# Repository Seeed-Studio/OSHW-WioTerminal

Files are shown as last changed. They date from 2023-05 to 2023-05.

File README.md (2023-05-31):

# Wio Terminal: Fabricatable Open Source Hardware

wio terminal

## Overview

Seeed Studio is committed to the open-source hardware movement, and in that spirit, we have taken this a step further into open manufacturing. We wish to make it possible for anyone to reproduce and manufacture this device. We believe that opening the manufacturing process will unlock immense potential for innovation and creativity.

Welcome to the Wio Terminal project, an open-source hardware initiative developed and maintained by Seeed Studio. The Wio Terminal is not just a highly integrated microcontroller, it is also a widely acknowledged and used IoT development platform. Compatible with Arduino and MicroPython, it supports both Bluetooth and Wi-Fi, providing strong support for IoT projects. Whether it is in smart homes, industrial automation, or educational research, Wio Terminal exhibits its powerful functionality and versatility.

With sincerity and practicality, we are now providing all the files and information required for manufacturing, enabling anyone to freely replicate, produce, and even commercialize the Wio Terminal. We believe that open manufacturing will facilitate innovation, allowing more people to participate in hardware design and improvement, and collectively promote the development of hardware technology. We look forward to seeing your versions and encourage you to share your designs and ideas on this platform.

## What we provided before

- The open source design files can be found in the ["resources" section](https://wiki.seeedstudio.com/Wio-Terminal-Getting-Started#resources) located below our products wiki.
- These design files are freely available for anyone to access, use and modify.

## What we are offering now

This repository contains all the necessary documentation you need to manufacture Wio Terminal:

- Schematic Diagrams (PDF)
- Gerber Files
- Firmware Source Code
- Bill of Materials (BOM)
- Production Testing Plan
- Production SOP
- 3D Models of the Enclosure

For the convenience, we also include here the design files in the Wio Terminal wiki.

## Documentation

For more information on the Wio Terminal, please refer to the following links:

- [Learn or Buy](https://www.seeedstudio.com/Wio-Terminal-p-4509.html)
- [Wio Terminal Wiki](https://wiki.seeedstudio.com/Wio-Terminal-Getting-Started)

## Fusion Quick Pass

For those who wish to design and manufacture their own versions of Wio Terminal, our [Fusion service](https://www.seeedstudio.com/fusion.html) offers quick and high-quality services. We also encourage you to share your own versions of Wio Terminal for display and exchange with the community.

## [A Chance To Get 2PCS Free PCBA from Seeed Fusion](https://www.seeedstudio.com/blog/2023/05/25/from-concept-to-creation-join-the-wio-terminal-movement-and-fabricate-your-own-open-source-hardware-for-a-chance-to-get-2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)

In order to give back to our community and make your great ideas a reality, Seeed Studio Fusion is launching the Wio Terminal open source movement to help capable engineers, individual developers turn their designs into real products.

For those who wish to design and manufacture their own versions of Wio Terminal, our SeeedStudio Fusion Agile manufacturing offers quick and high-quality PCB Assembly service. One more thing to clarify is that please make sure that you are capable of designing and have all the production files ready for us. Moreover, once your idea/proposal is approved by us, each person is limited to two PCBA boards 100% completely FREE for one Wio Terminal design, including PCB fabrication, the cost of parts, assembly and free worldwide delivery.

Please fill out the form: https://forms.gle/uic7bVA8SnuJLFR3A to submit your Wio Terminal design proposal. 

wioterminal

## License

This project is licensed under the [Apache-2.0 License](/LICENSE). By using, distributing, or contributing to this project, you agree to the terms and conditions of this license.

## Let's Open Manufacturing Together!

We're excited to take this journey with you. Let's create, innovate, and shape the future of open manufacturing together!

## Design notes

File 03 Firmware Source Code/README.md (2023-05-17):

Here is the firmware source code for Wio Terminal.

And here are the firmware source GitHub repositories links:

- Arduino-samd firmware for getting started with Wio Terminal: https://github.com/Seeed-Studio/ArduinoCore-samd

- SenseCraft firmware for supporting data Cloud upload: https://github.com/Seeed-Studio/SenseCraft

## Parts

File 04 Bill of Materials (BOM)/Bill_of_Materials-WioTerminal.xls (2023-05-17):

SKU | Spec | MPN | Reference | Base | Qty | Unit
102991299 | Wio Terminal (D51R)
202002756 | PCBA;Wio Terminal (D51R) |  |  | 1 | 1 | PCS
202002927 | PCBA;BT+WiFi Module;32P-L14*W12mm |  | U10 | 1 | 1 | PCS
206001065 | SMD IC NOR Flash;16Mbit-SPI;USON-8_software outsourcing_RTL8720DN v2.2 |  | U2 | 1 | 1 | PCS
310091053 | SMD IC NOR Flash;16Mbit-SPI;USON-8;2*3mm | GD25Q16CEIGR |  | 1 | 1 | PCS
301010525 | SMD RES 0R-±1%-1/20W;0201 | RC0201FR-070RL | L1, L2 | 1 | 2 | PCS
301010526 | SMD RES 10K-±1%-1/20W;0201 | RC0201FR-0710KL | R3, R8 | 1 | 2 | PCS
301010765 | SMD RES 100K-±1%-1/20W;0201 | RC0201FR-07100KL | R5 | 1 | 1 | PCS
302010053 | SMD CAP Ceramic 10uF-6.3V-20%-X5R;0402 | CC0402MRX5R5BB106 | C30 | 1 | 1 | PCS
302010233 | SMD CAP Ceramic 2.2uF-6.3V-20%-X5R;0402 | CC0402MRX5R5BB225 | C2, C3, C8 | 1 | 3 | PCS
302010271 | SMD CAP Ceramic 100nF-10V-10%-X5R;0201 | CC0201KRX5R6BB104 | C1, C4, C5, C6, C7, C9, C10, C11, C12, C18 | 1 | 10 | PCS
302010367 | SMD CAP Ceramic;10pF-25V-5%-NP0;0201 | CC0201JRNPO8BN100 | C19, C20 | 1 | 2 | PCS
302010730 | SMD CAP Ceramic 1uF-10V-20%-X5R;0201 | GRM033R61A105ME44D | C13, C15, C16 | 1 | 3 | PCS
302012228 | SMD CAP Ceramic 1pF±0.1pF-50V-COG/NPO;0201 | GRM0335C1H1R0BA01D | L3 | 1 | 1 | PCS
303010058 | SMD Inductor 2.2uH-20%-350mA;0402 | MLZ1005M2R2WT000 | L4 | 1 | 1 | PCS
306011034 | SMD Crystal 40MHz-10pF-10ppm-60R;4P-L2.0*W1.6mm | FA-128 40.000000MHZ 10PF 10PPM | X1 | 1 | 1 | PCS
306050436 | SMD Filter;6P 2.4G-5GHz 1.6*0.8*0.6mm | DPX165950DT-8148A1 | U3 | 1 | 1 | PCS
310011276 | SMD MCU;QFN48 | RTL8720DN-VA1-CG | U1 | 1 | 1 | PCS
319014199 | PCB;BT+WiFi Module_V1.1-black oil white legend-4 layers |  | PCB | 1 | 1 | PCS
323040420 | BT+WiFi Module_Shielding cover v3.0; 0.2mm white copper - laser engraving-13.5*11.5*1.7mm |  | SH1 | 1 | 1 | PCS
301010000 | SMD RES 0R-5%-1/16W;0402 | RC0402JR-070RL | R5, R8, R12, R17, R21, R39, R40, R41, R42, R46, R53, R68, R69, R72, R79, R83 | 1 | 16 | PCS
301010006 | SMD RES 1K-5%-1/16W;0402 | RC0402JR-071KL | R25, R28, R31, R47, R51, R88, R99 | 1 | 7 | PCS
301010010 | SMD RES 4.7K-5%-1/16W;0402 | RC0402JR-074K7L | R3, R4, R13, R11, R14, R20, R38, R48, R49, R54, R61, R62, R63 | 1 | 13 | PCS
301010047 | SMD RES 10K-1%-1/16W;0402 | RC0402FR-0710KL | R9, R22, R26, R27, R77, R94, R96, R97, R98 | 1 | 9 | PCS
301010052 | SMD RES 22R-1%-1/16W;0402 | RC0402FR-0722RL | R55, R56 | 1 | 2 | PCS
301010441 | SMD RES 33K-1%-1/16W;0402 | RC0402FR-0733KL | R71 | 1 | 1 | PCS
301010456 | SMD RES 100K-1%-1/16W;0402 | RC0402FR-07100KL | R7, R16, R18, R19, R23, R24, R29, R36, R37, R52, R78, R80, R84, R85, R86, R87, R91, R95, R100 | 1 | 19 | PCS
301010466 | SMD RES 330R-1%-1/16W;0402 | RC0402FR-07330RL | R30 | 1 | 1 | PCS
301010495 | SMD RES;5.1K-1%-1/16W;0402 | RC0402FR-075K1L | R1, R2 | 1 | 2 | PCS
301010609 | SMD RES;33R-1%-1/16W-0402 | RC0402FR-0733RL | R6, R35, R57, R66, R67, R74, R75, R76, R81, R82 | 1 | 10 | PCS
301011894 | SMD RES 150K-1%-1/16W;0402 | RC0402FR-07150KL | R70 | 1 | 1 | PCS
302010001 | SMD CAP Ceramic 10pF-50V-5%-NPO;0402 | CC0402JRNPO9BN100 | C12, C13, C42, C43 | 1 | 4 | PCS
302010004 | SMD CAP Ceramic 100nF-16V-10%-X7R;0402 | CC0402KRX7R7BB104 | C5, C7, C8, C10, C11, C14, C15, C29, C30, C31, C32, C33, C35, C36, C39, C48 | 1 | 16 | PCS
302010018 | SMD CAP Ceramic 22pF-50V-5%-NPO;0402 | CC0402JRNPO9BN220 | C49, C50 | 1 | 2 | PCS
302010040 | SMD CAP Ceramic 1uF-10V-10%-X5R;0402 | CC0402KRX5R6BB105 | C9, C16, C34, C37, C41, C53, C54, C55 | 1 | 8 | PCS
302010048 | SMD CAP Ceramic 0.5pF-50V-0.1pF-NPO;0402 | CC0402BRNPO9BNR50 | L3 | 1 | 1 | PCS
302010049 | SMD CAP Ceramic 12pF-50V-5%-NPO;0402 | CC0402JRNPO9BN120 | C51, C52 | 1 | 2 | PCS
302010053 | SMD CAP Ceramic 10uF-6.3V-20%-X5R;0402 | CC0402MRX5R5BB106 | C38, C40, C60, C61, C62, C64, C65, C66, C67 | 1 | 9 | PCS
302010103 | SMD CAP Ceramic 10uF-10V-10%-X5R;0603 | CC0603KRX5R6BB106 | C2, C3, C4 | 1 | 3 | PCS
302010411 | SMD CAP Ceramic 22uF-10V-20%-X5R;0603 | CC0603MRX5R6BB226 | C1, C6 | 1 | 2 | PCS
302020008 | SMD CAP Tantalum 22uF-10V;A | TAJA226K010RNJ | C63 | 1 | 1 | PCS
303010090 | SMD Inductor;2.2uH-±20%-600mA;0805 | MLZ2012M2R2HT000 | L2 | 1 | 1 | PCS
303010622 | SMD Inductor 10uH-1A-20%;1008 | 1239AS-H-100M=P2 | L6 | 1 | 1 | PCS
303010943 | SMD Inductor;1.2uH-20%-2.1A-2.5*2.0*1.2mm | SPH252012H1R2MT | L5 | 1 | 1 | PCS
303030201 | SMD Ferrite Bead 120R-1.2A;0402 | MPZ1005S121CT000 | FB2, FB3, R43, R44, R45 | 1 | 5 | PCS
304020048 | SMD Diode Schottky;SOD-323 | B5819WS | D5, D9 | 1 | 2 | PCS
304050025 | SMD Diode TVS 3.3VWM-11.5V;SOD-923 | ESD9B3.3ST5G | D1, D6, D8 | 1 | 3 | PCS
304050806 | SMD Diode TVS;5V-4A;uDFN-14 | SP3012-06UTG | D15 | 1 | 1 | PCS
304060074 | SMD Diode ESD 0.05pF;0402 | ESDPSA0402V05 | D2, D3, D4 | 1 | 3 | PCS
304090021 | SMD LED Clear-Blue;0603 | 27-21/BHC-AN1P2/3C | D7 | 1 | 1 | PCS
304090030 | SMD LED Clear-Green;0603 | 27-21/GHC-YR1S2M/3C | LED1 | 1 | 1 | PCS
305030010 | SMD MOSFET P-CH 30V-4.3A;SOT-23 | CJ3407 | Q2, Q7, Q8, Q9, Q10, Q12, Q14, Q15 | 1 | 8 | PCS
305030028 | SMD MOSFET N-CH 60V-300mA ;SOT-23 | 2N7002,215 | Q1, Q3, Q4, Q13, Q16 | 1 | 5 | PCS
305050111 | SMD Transistor Array 2 PNP -65V-100mA;SOT-363 | BC856S | Q11 | 1 | 1 | PCS
306010020 | SMD Crystal 32.768KHz-12.5pF-20ppm-90K;2P-L2.05*W1.2*H0.6mm | FC-12M 32.7680KA-A3 | X2 | 1 | 1 | PCS
306011033 | SMD Crystal 32MHz-8pF-10ppm;4P-L3.2mm*W2.5mm | S3232000081040 | X4 | 1 | 1 | PCS
307010517 | SMD PTC 3A-6V;1206 | 1206L300SLTHYR | F1 | 1 | 1 | PCS
308010340 | LCD 42.72*60.26-white-FPC;L48.96*W36.72*H2.2mm-19.65mm | QY24009A0-04 | U4 | 1 | 1 | PCS
310011218 | SMD IC MCU;TFBGA-120 | ATSAMD51P19A-CTUT | U1 | 1 | 1 | PCS
310020007 | SMD IC Amplifier;MSOP-8 | LMV358IDGKR | U2 | 1 | 1 | PCS
310030245 | SMD IC PMIC;LDO-3.3V-600mA;SOT23-5 | AP2112K-3.3TRG1 | U13 | 1 | 1 | PCS
310031334 | SMD IC PMIC;DCDC Buck-ADJ-2A;TSOT23-8 | MP2161GJ | U12 | 1 | 1 | PCS
310050019 | SMD IC Logic;SC-70-5 | SN74LVC1G125DCKR | U9 | 1 | 1 | PCS
310090667 | SMD IC Memory;SOIC-8 | W25Q32JVSSIQ | U14 | 1 | 1 | PCS
311010460 | SMD Side Toggle Switch SPDT;4P+2P-L12.7*W3.0*H2mm-90D | MK-13E23Q-G | SW3 | 1 | 1 | PCS
311020318 | SMD Side Button 180gf;4P-L4.8*W2.35*H2.3mm-90D | TS-1111A(Black) | K1, K2, K3 | 1 | 3 | PCS
311110128 | SMD Joystick;8P-L7.5*W7.5*H6mm | BLQ-1502-01-06 | SW1 | 1 | 1 | PCS
312020683 | SMD Buzzer 3V;3P-L5.0*W5.0*H2mm | LET5020DS-03L-4.0-12-R | BUZ1 | 1 | 1 | PCS
312030402 | SMD Mic OMI -42dB;2P-D4-H1.3mm | B4013AM422-42 | MIC1 | 1 | 1 | PCS
314020381 | SMD Optical Sensor;3.2*2.8*3.5mm | SG-A1DPHY | U8 | 1 | 1 | PCS
314020624 | SMD IR Emitter Sensor;0603 | E6C0603IRAC1UDA | D10 | 1 | 1 | PCS
314080105 | SMD Motion & Position Sensor;LGA-16 | LIS3DHTR | U5 | 1 | 1 | PCS
319014201 | PCB;Wio Terminal (D51R ) v2.1-black oil white legend-4 layers |  | PCB | 1 | 1 | PCS
320010943 | SMD USB Type-c;12P+4-8.9*7.3*3.2mm | UBF31-0171 | USB1 | 1 | 1 | PCS
320031024 | SMD Black Female Header;2*20P-2.54-7.1mm | ST-0265 | U3 | 1 | 1 | PCS
320060144 | SMD FPC CONN;20P-0.5 | XW05200-20 | J6 | 1 | 1 | PCS
320060626 | SMD FPC CONN;1*10P-0.5mm | YL002-001-010 | J3 | 1 | 1 | PCS
320090000 | SMD SD Card Holder;9P-L14.7*W13.8*H1.0mm | ST-TF-003J | J1 | 1 | 1 | PCS
320110032 | SMD Grove Female Header-Beige;4P-2.0-90D | PHS-4A | J4, J5 | 1 | 2 | PCS
321010557 | USB Cable;Type A to Type C - 200mm |  |  | 1 | 1 | PCS
322011086 | Wio Terminal_Transparent window on main control back cover V1.0; 2.5mm thick transparent tempered acrylic-30.3*30.23*2.5mm |  |  | 1 | 1 | PCS
322011429 | Wio Terminal_Main control front cover screen panel V4.0_0.8mm thick transparent tempered acrylic_69.56*49.01*0.8mm |  |  | 1 | 1 | PCS
322070840 | Wio Terminal_Main control button cap V2.0; ABS-blue-sun-fine lines-35.56*7.8*3.99mm |  |  | 1 | 1 | PCS
322070863 | Wio Terminal_Main control middle frame V3.1; ABS-white-sun-fine lines-72*57*10.4mm |  |  | 1 | 1 | PCS
322070864 | Wio Terminal_Main control back cover V3.0; ABS-white-sun-fine lines-72*57*7.1mm |  |  | 1 | 1 | PCS
322070867 | Wio Terminal_Main control joystick button cap V3.0; ABS-blue-sun-fine lines-D7.95*3.9mm |  |  | 1 | 2 | PCS
322070868 | Wio Terminal_Main control female screw sleeve V3.1; ABS-blue-sun-fine lines-56.35x10.15x6.4mm |  |  | 1 | 1 | PCS
322070873 | Wio Terminal_Main control toggle switch key V4.0; ABS-white-sun-fine lines-13.3*7.1*4.05mm |  |  | 1 | 1 | PCS
322100425 | Silicone pad; black silicone-D5*H1mm |  |  | 1 | 4 | PCS
323020266 | Magnet; N52 strong magnet-D5*H3mm |  |  | 1 | 4 | PCS
326010846 | Screw;Cross recessed countersunk flat tail machine thread screw - KM2*H10.0 - black zinc plated |  |  | 1 | 2 | PCS
326010867 | Screw;Black-Cross recessed flat head self-tapping screw-CA1.4*3mm |  |  | 1 | 1 | PCS
327040015 | Plastic Bag Clear;W40*H60*0.05mm-Self-sealing bag - red edge |  |  | 1 | 1 | PCS
327040403 | CPE self-sealing frosted bag; 80 (opening)*100*0.08mm+30mm |  |  | 1 | 1 | PCS
327110729 | Packing box C10; K=K-500370270mm (with company logo; with quality and strength stamp; with anti-damage marking) |  |  | 108 | 1 | PCS
327111193 | Wio Terminal_Kraft paper box; 250g kraft paper mounted with AF pits-115*86*30mm |  |  | 1 | 1 | PCS
327121960 | Wio Terminal_Envelope v2.0; 350g white cardboard + matte film-253*115mm |  |  | 1 | 1 | PCS
327130059 | CH_Label;Self-adhesive copperplate paper - L40*W30mm (double column |  |  | 1 | 1 | PCS
327130462 | Label;Non-removable transparent round sticker - D30mm - high adhesive |  |  | 1 | 2 | PCS
327132374 | Wio Terminal_Back cover sticker V2.0; 54# synthetic sticker + matte film-25.8*23.8mm |  |  | 1 | 1 | PCS
327132375 | BT+WiFi Module_Shielding cover sticker v1.1; 54# synthetic sticker + matte film-13.0*11.0mm |  |  | 1 | 1 | PCS
327132400 | Wio Terminal _Sticker v1.0; 80g self-adhesive sticker + matte film-70*90mm |  |  | 1 | 1 | PCS
327140436 | C10_pearl cotton 1; white pearl cotton-485*335*10mm |  |  | 108 | 2 | PCS
327140437 | C10_pearl cotton 2; white pearl cotton-485*230*10mm |  |  | 108 | 2 | PCS
327140438 | C10_pearl cotton 3; white pearl cotton-305*230*10mm |  |  | 108 | 2 | PCS
327141503 | Dust-proof foam_3M adhesive on one side+PET film_Hardness24P-57.5*42.3*0.3mm |  |  | 1 | 1 | PCS
327171500 | Wio Terminal_Instruction manual v2.1; cover and back cover 128g copperplate paper + inner pages 80g book paper - saddle stitch binding-70*90mm |  |  | 1 | 1 | PCS
401040192 | S300 plastic adhesive; 20g/bottle |  |  | 150 | 1 | Tube
401040231 | UV glue - Weichang - DDY6203_6 - colorless and transparent - 50ml |  |  | 550 | 1 | PCS
403990199 | Weichang reactive polyurethane hot melt adhesive - FCD-6863 - 35g/tube |  |  | 160 | 1 | PCS

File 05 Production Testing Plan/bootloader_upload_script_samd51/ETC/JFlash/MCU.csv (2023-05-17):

Manufacturer | Name | FlashDevice | DeviceFamily | BetaSupport | ExternalBus | Endian | CoreId | BaseAddr | RAMAddr | RAMSize
Abov | AC33M6128L | AC33M8128 internal | 030000FF | 0 | 0 | 0 | 4BA00477 | 0 | 20000000 | 3000
Abov | AC33M8128 | AC33M8128 internal | 030000FF | 0 | 0 | 0 | 4BA00477 | 0 | 20000000 | 3000
Abov | AC33M8128L | AC33M8128 internal | 030000FF | 0 | 0 | 0 | 4BA00477 | 0 | 20000000 | 3000
Actel | A2F060M3E | A2FxxxM3E internal | 030000FF | 0 | 0 | 0 | 3BA00477 | 60000000 | 20000000 | 4000
Actel | A2F060M3F | A2FxxxM3F internal | 030000FF | 0 | 0 | 0 | 3BA00477 | 60000000 | 20000000 | 4000
Actel | A2F060M3G | A2FxxxM3G internal | 030000FF | 0 | 0 | 0 | 3BA00477 | 60000000 | 20000000 | 4000
Actel | A2F200M3E | A2FxxxM3E internal | 030000FF | 0 | 0 | 0 | 3BA00477 | 60000000 | 20000000 | 10000
Actel | A2F200M3F | A2FxxxM3F internal | 030000FF | 0 | 0 | 0 | 3BA00477 | 60000000 | 20000000 | 10000
Actel | A2F200M3G | A2FxxxM3G internal | 030000FF | 0 | 0 | 0 | 3BA00477 | 60000000 | 20000000 | 10000
Actel | A2F500M3E | A2FxxxM3E internal | 030000FF | 0 | 0 | 0 | 3BA00477 | 60000000 | 20000000 | 10000
Actel | A2F500M3F | A2FxxxM3F internal | 030000FF | 0 | 0 | 0 | 3BA00477 | 60000000 | 20000000 | 10000
Actel | A2F500M3G | A2FxxxM3G internal | 030000FF | 0 | 0 | 0 | 3BA00477 | 60000000 | 20000000 | 10000
active-semi | PAC5210 | PAC52xx internal | 060000FF | 0 | 0 | 0 | 0BB11477 | 0 | 20000000 | 2000
active-semi | PAC5220 | PAC52xx internal | 060000FF | 0 | 0 | 0 | 0BB11477 | 0 | 20000000 | 2000
active-semi | PAC5220WP | PAC52xx internal | 060000FF | 0 | 0 | 0 | 0BB11477 | 0 | 20000000 | 2000
active-semi | PAC5223 | PAC52xx internal | 060000FF | 0 | 0 | 0 | 0BB11477 | 0 | 20000000 | 2000
active-semi | PAC5250 | PAC52xx internal | 060000FF | 0 | 0 | 0 | 0BB11477 | 0 | 20000000 | 2000
active-semi | PAC5253 | PAC52xx internal | 060000FF | 0 | 0 | 0 | 0BB11477 | 0 | 20000000 | 2000
Altera | Cyclone V |  | 080900FF | 0 | 1 | 2 | 4BA00477 | 000000000 | FFFF0000 | 10000
AmbiqMicro | APOLLO512 | APOLLO512 internal | 0E0000FF | 0 | 1 | 0 | 2BA00477 | 0 | 10000000 | 10000
AmbiqMicro | APOLLO256 | APOLLO256 internal | 0E0000FF | 0 | 1 | 0 | 2BA00477 | 0 | 10000000 | 8000
AmbiqMicro | APOLLO128 | APOLLO128 internal | 0E0000FF | 0 | 1 | 0 | 2BA00477 | 0 | 10000000 | 8000
AmbiqMicro | APOLLO064 | APOLLO064 internal | 0E0000FF | 0 | 1 | 0 | 2BA00477 | 0 | 10000000 | 4000
AMS | AS7000 | AS7000 internal | 060000FF | 0 | 0 | 0 | 0BB11477 | 30000000 | 20000000 | 1000
Analog | AD7160 | AD7160 internal | 030000FF | 0 | 1 | 0 | 2BA01477 | 0 | 20000000 | 1000
Analog | ADuC7020x62 | ADuC702xx62 internal | 070000FF | 0 | 0 | 0 | 3F0F0F0F | 80000 | 10000 | 2000
Analog | ADuC7021x32 | ADuC702xx32 internal | 070000FF | 0 | 0 | 0 | 3F0F0F0F | 80000 | 10000 | 1000
Analog | ADuC7021x62 | ADuC702xx62 internal | 070000FF | 0 | 0 | 0 | 3F0F0F0F | 80000 | 10000 | 2000
Analog | ADuC7022x32 | ADuC702xx32 internal | 070000FF | 0 | 0 | 0 | 3F0F0F0F | 80000 | 10000 | 1000
Analog | ADuC7022x62 | ADuC702xx62 internal | 070000FF | 0 | 0 | 0 | 3F0F0F0F | 80000 | 10000 | 2000
Analog | ADuC7023 | ADuC7023 internal | 070000FF | 0 | 0 | 0 | 4F1F0F0F | 80000 | 10000 | 2000
Analog | ADuC7024x62 | ADuC702xx62 internal | 070000FF | 0 | 0 | 0 | 3F0F0F0F | 80000 | 10000 | 2000
Analog | ADuC7025x32 | ADuC702xx32 internal | 070000FF | 0 | 0 | 0 | 3F0F0F0F | 80000 | 10000 | 1000
Analog | ADuC7025x62 | ADuC702xx62 internal | 070000FF | 0 | 0 | 0 | 3F0F0F0F | 80000 | 10000 | 2000
Analog | ADuC7026x62 | ADuC702xx62 internal | 070000FF | 0 | 1 | 0 | 3F0F0F0F | 80000 | 10000 | 2000
Analog | ADuC7027x62 | ADuC702xx62 internal | 070000FF | 0 | 1 | 0 | 3F0F0F0F | 80000 | 10000 | 2000
Analog | ADuC7028x62 | ADuC7028x62 internal | 070000FF | 0 | 1 | 0 | 3F0F0F0F | 80000 | 10000 | 2000
Analog | ADuC7030 | ADuC7030 internal | 070000FF | 0 | 1 | 0 | 3F0F0F0F | 80000 | 40000 | 1000
Analog | ADuC7031 | ADuC7031 internal | 070000FF | 0 | 1 | 0 | 3F0F0F0F | 80000 | 40000 | 1000
Analog | ADuC7032 | ADuC7032 internal | 070000FF | 0 | 1 | 0 | 3F0F0F0F | 80000 | 40000 | 1800
Analog | ADuC7033 | ADuC7033 internal | 070000FF | 0 | 1 | 0 | 3F0F0F0F | 80000 | 40000 | 1800
Analog | ADuC7034 | ADuC7034 internal | 070000FF | 0 | 1 | 0 | 3F0F0F0F | 80000 | 40000 | 1000
Analog | ADuC7036 | ADuC7036 internal | 070000FF | 0 | 1 | 0 | 3F0F0F0F | 80000 | 40000 | 1800
Analog | ADuC7038 | ADuC7038 internal | 070001FF | 0 | 1 | 0 | 127E91CB | 80000 | 40000 | 1000
Analog | ADuC7039 | ADuC7039 internal | 070001FF | 0 | 1 | 0 | 227E91CB | 80000 | 40000 | 1000
Analog | ADuC7060 | ADuC7060 internal | 070000FF | 0 | 1 | 0 | 3F0F0F0F | 80000 | 40000 | 1000
Analog | ADuC7061 | ADuC7061 internal | 070000FF | 0 | 1 | 0 | 3F0F0F0F | 80000 | 40000 | 1000
Analog | ADuC7062 | ADuC7062 internal | 070000FF | 0 | 1 | 0 | 3F0F0F0F | 80000 | 40000 | 1000
Analog | ADuC7121 | ADuC7121 internal | 070000FF | 0 | 1 | 0 | 3F0F0F0F | 80000 | 40000 | 2000
Analog | ADuC7122 | ADuC7122 internal | 070000FF | 0 | 1 | 0 | 3F0F0F0F | 80000 | 40000 | 2000
Analog | ADuC7124 | ADuC7124 internal | 070000FF | 0 | 1 | 0 | 4F1F0F0F | 80000 | 40000 | 8000
Analog | ADuC7128 | ADuC7128 internal | 070000FF | 0 | 1 | 0 | 3F0F0F0F | 80000 | 40000 | 2000
Analog | ADuC7129 | ADuC7129 internal | 070000FF | 0 | 1 | 0 | 3F0F0F0F | 80000 | 40000 | 2000
Analog | ADuC7229x126 | ADuC722xx126 internal | 070000FF | 0 | 1 | 0 | 3F0F0F0F | 80000 | 40000 | 2000
Analog | ADuCM301 | ADuCM301 internal | 030000FF | 0 | 1 | 0 | 2BA01477 | 0 | 20000000 | 2000
Analog | ADuCM310 | ADuCM310 internal | 030000FF | 0 | 1 | 0 | 2BA01477 | 0 | 20000000 | 8000
Analog | ADuCM320 | ADuCM320 internal | 030000FF | 0 | 1 | 0 | 2BA01477 | 0 | 20000000 | 8000
Analog | ADuCM330 | ADuCM330 internal | 030000FF | 0 | 1 | 0 | 2BA01477 | 0 | 20000000 | 1800
Analog | ADuCM331 | ADuCM331 internal | 030000FF | 0 | 1 | 0 | 2BA01477 | 0 | 20000000 | 1800
Analog | ADuCM332 | ADuCM332 internal | 030000FF | 0 | 1 | 0 | 2BA01477 | 0 | 20000000 | 1800
Analog | ADuCM350 | ADuCM350 internal | 030000FF | 0 | 1 | 0 | 2BA01477 | 0 | 20000000 | 4000
Analog | ADuCM360 | ADuCM360 internal | 030000FF | 0 | 1 | 0 | 2BA01477 | 0 | 20000000 | 2000
Analog | ADuCM361 | ADuCM361 internal | 030000FF | 0 | 1 | 0 | 2BA01477 | 0 | 20000000 | 2000
Analog | ADuCM362 | ADuCM362 internal | 030000FF | 0 | 1 | 0 | 2BA01477 | 0 | 20000000 | 6000
Analog | ADuCRF02 | ADuCRF02 internal | 030000FF | 0 | 1 | 0 | 2BA01477 | 0 | 20000000 | 2000
Analog | ADuCRF101 | ADuCRF101 internal | 030000FF | 0 | 1 | 0 | 2BA01477 | 0 | 20000000 | 4000
Analog | ADSP-CM402BSWZ-EF | ADSP-CM402BSWZ-EF internal | 030000FF | 0 | 1 | 0 | 2BA01477 | 18000000 | 10000000 | 10000
Analog | ADSP-CM402BSWZ-FF | ADSP-CM402BSWZ-FF internal | 030000FF | 0 | 1 | 0 | 2BA01477 | 18000000 | 10000000 | 10000
Analog | ADSP-CM403BSWZ-CF | ADSP-CM403BSWZ-CF internal | 030000FF | 0 | 1 | 0 | 2BA01477 | 18000000 | 10000000 | 10000
Analog | ADSP-CM403BSWZ-EF | ADSP-CM403BSWZ-EF internal | 030000FF | 0 | 1 | 0 | 2BA01477 | 18000000 | 10000000 | 10000
Analog | ADSP-CM403BSWZ-FF | ADSP-CM403BSWZ-FF internal | 030000FF | 0 | 1 | 0 | 2BA01477 | 18000000 | 10000000 | 10000
Analog | ADSP-CM407BSWZ-AF | ADSP-CM407BSWZ-AF internal | 030000FF | 0 | 1 | 0 | 2BA01477 | 18000000 | 10000000 | 10000
Analog | ADSP-CM407BSWZ-BF | ADSP-CM407BSWZ-BF internal | 030000FF | 0 | 1 | 0 | 2BA01477 | 18000000 | 10000000 | 10000
Analog | ADSP-CM407BSWZ-DF | ADSP-CM407BSWZ-DF internal | 030000FF | 0 | 1 | 0 | 2BA01477 | 18000000 | 10000000 | 10000
Analog | ADSP-CM408BSWZ-AF | ADSP-CM408BSWZ-AF internal | 030000FF | 0 | 1 | 0 | 2BA01477 | 18000000 | 10000000 | 10000
Analog | ADSP-CM408BSWZ-BF | ADSP-CM408BSWZ-BF internal | 030000FF | 0 | 1 | 0 | 2BA01477 | 18000000 | 10000000 | 10000
Analog | ADSP-CM409BSWZ-AF | ADSP-CM409BSWZ-AF internal | 0E0000FF | 0 | 1 | 0 | 2BA01477 | 18000000 | 10000000 | 18000
Analog | ADSP-CM409BSWZ-BF | ADSP-CM409BSWZ-BF internal | 0E0000FF | 0 | 1 | 0 | 2BA01477 | 18000000 | 10000000 | 18000
Atmel | ATSAM3A2C | AT91SAM3A2 internal | 030000FF | 0 | 0 | 0 | 4BA00477 | 80000 | 20000000 | 4000
Atmel | ATSAM3A4C | AT91SAM3A4 internal | 030000FF | 0 | 0 | 0 | 4BA00477 | 80000 | 20000000 | 8000
Atmel | ATSAM3A8C | AT91SAM3A8 internal | 030000FF | 0 | 0 | 0 | 4BA00477 | 80000 | 20000000 | 10000
Atmel | ATSAM3N00A | AT91SAM3N00 internal | 030000FF | 0 | 0 | 0 | 4BA00477 | 400000 | 20000000 | 1000
Atmel | ATSAM3N00B | AT91SAM3N00 internal | 030000FF | 0 | 0 | 0 | 4BA00477 | 400000 | 20000000 | 1000
Atmel | ATSAM3N0A | AT91SAM3N0 internal | 030000FF | 0 | 0 | 0 | 4BA00477 | 400000 | 20000000 | 2000
Atmel | ATSAM3N0B | AT91SAM3N0 internal | 030000FF | 0 | 0 | 0 | 4BA00477 | 400000 | 20000000 | 2000
Atmel | ATSAM3N0C | AT91SAM3N0 internal | 030000FF | 0 | 0 | 0 | 4BA00477 | 400000 | 20000000 | 2000
Atmel | ATSAM3N1A | AT91SAM3N1 internal | 030000FF | 0 | 0 | 0 | 4BA00477 | 400000 | 20000000 | 2000
Atmel | ATSAM3N1B | AT91SAM3N1 internal | 030000FF | 0 | 0 | 0 | 4BA00477 | 400000 | 20000000 | 2000
Atmel | ATSAM3N1C | AT91SAM3N1 internal | 030000FF | 0 | 0 | 0 | 4BA00477 | 400000 | 20000000 | 2000
Atmel | ATSAM3N2A | AT91SAM3N2 internal | 030000FF | 0 | 0 | 0 | 4BA00477 | 400000 | 20000000 | 4000
Atmel | ATSAM3N2B | AT91SAM3N2 internal | 030000FF | 0 | 0 | 0 | 4BA00477 | 400000 | 20000000 | 4000
Atmel | ATSAM3N2C | AT91SAM3N2 internal | 030000FF | 0 | 0 | 0 | 4BA00477 | 400000 | 20000000 | 4000
Atmel | ATSAM3N4A | AT91SAM3N4 internal | 030000FF | 0 | 0 | 0 | 4BA00477 | 400000 | 20000000 | 6000
Atmel | ATSAM3N4B | AT91SAM3N4 internal | 030000FF | 0 | 0 | 0 | 4BA00477 | 400000 | 20000000 | 6000
Atmel | ATSAM3N4C | AT91SAM3N4 internal | 030000FF | 0 | 0 | 0 | 4BA00477 | 400000 | 20000000 | 6000
Atmel | ATSAM3S1A | AT91SAM3S1 internal | 030000FF | 0 | 0 | 0 | 4BA00477 | 400000 | 20000000 | 4000
Atmel | ATSAM3S1B | AT91SAM3S1 internal | 030000FF | 0 | 0 | 0 | 4BA00477 | 400000 | 20000000 | 4000
Atmel | ATSAM3S1C | AT91SAM3S1 internal | 030000FF | 0 | 0 | 0 | 4BA00477 | 400000 | 20000000 | 4000
Atmel | ATSAM3S2A | AT91SAM3S2 internal | 030000FF | 0 | 0 | 0 | 4BA00477 | 400000 | 20000000 | 8000
Atmel | ATSAM3S2B | AT91SAM3S2 internal | 030000FF | 0 | 0 | 0 | 4BA00477 | 400000 | 20000000 | 8000
Atmel | ATSAM3S2C | AT91SAM3S2 internal | 030000FF | 0 | 0 | 0 | 4BA00477 | 400000 | 20000000 | 8000
Atmel | ATSAM3S4A | AT91SAM3S4 internal | 030000FF | 0 | 0 | 0 | 4BA00477 | 400000 | 20000000 | C000
Atmel | ATSAM3S4B | AT91SAM3S4 internal | 030000FF | 0 | 0 | 0 | 4BA00477 | 400000 | 20000000 | C000
Atmel | ATSAM3S4C | AT91SAM3S4 internal | 030000FF | 0 | 0 | 0 | 4BA00477 | 400000 | 20000000 | C000
Atmel | ATSAM3S8B | AT91SAM3S8 internal | 030000FF | 0 | 0 | 0 | 4BA00477 | 400000 | 20000000 | 10000
Atmel | ATSAM3S8C | AT91SAM3S8 internal | 030000FF | 0 | 0 | 0 | 4BA00477 | 400000 | 20000000 | 10000
Atmel | ATSAM3SD8B | AT91SAM3S8 internal | 030000FF | 0 | 0 | 0 | 4BA00477 | 400000 | 20000000 | 10000
Atmel | ATSAM3SD8C | AT91SAM3S8 internal | 030000FF | 0 | 0 | 0 | 4BA00477 | 400000 | 20000000 | 10000
Atmel | ATSAM3U1C | AT91SAM3U1 internal | 030000FF | 0 | 0 | 0 | 4BA00477 | 80000 | 20000000 | 2000
Atmel | ATSAM3U2C | AT91SAM3U2 internal | 030000FF | 0 | 0 | 0 | 4BA00477 | 80000 | 20000000 | 4000
Atmel | ATSAM3U4C | AT91SAM3U4 internal | 030000FF | 0 | 0 | 0 | 4BA00477 | 80000 | 20000000 | 8000
Atmel | ATSAM3U1E | AT91SAM3U1 internal | 030000FF | 0 | 0 | 0 | 4BA00477 | 80000 | 20000000 | 2000
Atmel | ATSAM3U2E | AT91SAM3U2 internal | 030000FF | 0 | 0 | 0 | 4BA00477 | 80000 | 20000000 | 4000
Atmel | ATSAM3U4E | AT91SAM3U4 internal | 030000FF | 0 | 0 | 0 | 4BA00477 | 80000 | 20000000 | 8000
Atmel | ATSAM3X2C | AT91SAM3X2 internal | 030000FF | 0 | 0 | 0 | 4BA00477 | 80000 | 20000000 | 4000
Atmel | ATSAM3X2E | AT91SAM3X2 internal | 030000FF | 0 | 0 | 0 | 4BA00477 | 80000 | 20000000 | 4000
Atmel | ATSAM3X2G | AT91SAM3X2 internal | 030000FF | 0 | 0 | 0 | 4BA00477 | 80000 | 20000000 | 4000
Atmel | ATSAM3X2H | AT91SAM3X2 internal | 030000FF | 0 | 0 | 0 | 4BA00477 | 80000 | 20000000 | 4000
Atmel | ATSAM3X4C | AT91SAM3X4 internal | 030000FF | 0 | 0 | 0 | 4BA00477 | 80000 | 20000000 | 8000
Atmel | ATSAM3X4E | AT91SAM3X4 internal | 030000FF | 0 | 0 | 0 | 4BA00477 | 80000 | 20000000 | 8000
Atmel | ATSAM3X4G | AT91SAM3X4 internal | 030000FF | 0 | 0 | 0 | 4BA00477 | 80000 | 20000000 | 8000
Atmel | ATSAM3X4H | AT91SAM3X4 internal | 030000FF | 0 | 0 | 0 | 4BA00477 | 80000 | 20000000 | 8000
Atmel | ATSAM3X8C | AT91SAM3X8 internal | 030000FF | 0 | 0 | 0 | 4BA00477 | 80000 | 20000000 | 10000
Atmel | ATSAM3X8E | AT91SAM3X8 internal | 030000FF | 0 | 0 | 0 | 4BA00477 | 80000 | 20000000 | 10000
Atmel | ATSAM3X8G | AT91SAM3X8 internal | 030000FF | 0 | 0 | 0 | 4BA00477 | 80000 | 20000000 | 10000
Atmel | ATSAM3X8H | AT91SAM3X8 internal | 030000FF | 0 | 0 | 0 | 4BA00477 | 80000 | 20000000 | 10000
Atmel | ATSAM4N8A | AT91SAM4N8 internal | 0E0000FF | 0 | 0 | 0 | 4BA00477 | 400000 | 20000000 | 10000
Atmel | ATSAM4N8B | AT91SAM4N8 internal | 0E0000FF | 0 | 0 | 0 | 4BA00477 | 400000 | 20000000 | 10000
Atmel | ATSAM4N8C | AT91SAM4N8 internal | 0E0000FF | 0 | 0 | 0 | 4BA00477 | 400000 | 20000000 | 10000
Atmel | ATSAM4N16B | AT91SAM4N16 internal | 0E0000FF | 0 | 0 | 0 | 4BA00477 | 400000 | 20000000 | 14000
Atmel | ATSAM4N16C | AT91SAM4N16 internal | 0E0000FF | 0 | 0 | 0 | 4BA00477 | 400000 | 20000000 | 14000
Atmel | ATSAM4S2A | AT91SAM4S2 internal | 0E0000FF | 0 | 0 | 0 | 4BA00477 | 400000 | 20000000 | 10000
Atmel | ATSAM4S2B | AT91SAM4S2 internal | 0E0000FF | 0 | 0 | 0 | 4BA00477 | 400000 | 20000000 | 10000
Atmel | ATSAM4S2C | AT91SAM4S2 internal | 0E0000FF | 0 | 0 | 0 | 4BA00477 | 400000 | 20000000 | 10000
Atmel | ATSAM4S4A | AT91SAM4S4 internal | 0E0000FF | 0 | 0 | 0 | 4BA00477 | 400000 | 20000000 | 10000
Atmel | ATSAM4S4B | AT91SAM4S4 internal | 0E0000FF | 0 | 0 | 0 | 4BA00477 | 400000 | 20000000 | 10000
Atmel | ATSAM4S4C | AT91SAM4S4 internal | 0E0000FF | 0 | 0 | 0 | 4BA00477 | 400000 | 20000000 | 10000
Atmel | ATSAM4S8A | AT91SAM4S8 internal | 0E0000FF | 0 | 0 | 0 | 4BA00477 | 400000 | 20000000 | 20000
Atmel | ATSAM4S8B | AT91SAM4S8 internal | 0E0000FF | 0 | 0 | 0 | 4BA00477 | 400000 | 20000000 | 20000
Atmel | ATSAM4S8C | AT91SAM4S8 internal | 0E0000FF | 0 | 0 | 0 | 4BA00477 | 400000 | 20000000 | 20000
Atmel | ATSAM4S16A | AT91SAM4S16 internal | 0E0000FF | 0 | 0 | 0 | 4BA00477 | 400000 | 20000000 | 20000
Atmel | ATSAM4S16B | AT91SAM4S16 internal | 0E0000FF | 0 | 0 | 0 | 4BA00477 | 400000 | 20000000 | 20000
Atmel | ATSAM4S16C | AT91SAM4S16 internal | 0E0000FF | 0 | 0 | 0 | 4BA00477 | 400000 | 20000000 | 20000
Atmel | ATSAM4SA16B | AT91SAM4SA16 internal | 0E0000FF | 0 | 0 | 0 | 4BA00477 | 400000 | 20000000 | 28000
Atmel | ATSAM4SA16C | AT91SAM4SA16 internal | 0E0000FF | 0 | 0 | 0 | 4BA00477 | 400000 | 20000000 | 28000
Atmel | ATSAM4SD16B | AT91SAM4SD16 internal | 0E0000FF | 0 | 0 | 0 | 4BA00477 | 400000 | 20000000 | 28000
Atmel | ATSAM4SD16C | AT91SAM4SD16 internal | 0E0000FF | 0 | 0 | 0 | 4BA00477 | 400000 | 20000000 | 28000
Atmel | ATSAM4SD32B | AT91SAM4SD32 internal | 0E0000FF | 0 | 0 | 0 | 4BA00477 | 400000 | 20000000 | 28000
Atmel | ATSAM4SD32C | AT91SAM4SD32 internal | 0E0000FF | 0 | 0 | 0 | 4BA00477 | 400000 | 20000000 | 28000
Atmel | ATSAM4SP32A | AT91SAM4SP32 internal | 0E0000FF | 0 | 0 | 0 | 4BA00477 | 400000 | 20000000 | 28000
Atmel | ATSAM4C4C | ATSAM4C4x internal | 0E0000FF | 0 | 0 | 0 | 4BA00477 | 1000000 | 20000000 | 20000
Atmel | ATSAM4C8C | ATSAM4C8x internal | 0E0000FF | 0 | 0 | 0 | 4BA00477 | 1000000 | 20000000 | 20000
Atmel | ATSAM4C16C | ATSAM4C16x internal | 0E0000FF | 0 | 0 | 0 | 4BA00477 | 1000000 | 20000000 | 20000
Atmel | ATSAM4C32C | ATSAM4C32x internal | 0E0000FF | 0 | 0 | 0 | 4BA00477 | 1000000 | 20000000 | 20000
Atmel | ATSAM4C32E | ATSAM4C32x internal | 0E0000FF | 0 | 0 | 0 | 4BA00477 | 1000000 | 20000000 | 20000
Atmel | ATSAM4CMP8C | ATSAM4C8x internal | 0E0000FF | 0 | 0 | 0 | 4BA00477 | 1000000 | 20000000 | 20000
Atmel | ATSAM4CMP16C | ATSAM4C16x internal | 0E0000FF | 0 | 0 | 0 | 4BA00477 | 1000000 | 20000000 | 20000
Atmel | ATSAM4CMP32C | ATSAM4C32x internal | 0E0000FF | 0 | 0 | 0 | 4BA00477 | 1000000 | 20000000 | 20000
Atmel | ATSAM4CMS4C | ATSAM4C4x internal | 0E0000FF | 0 | 0 | 0 | 4BA00477 | 1000000 | 20000000 | 20000
Atmel | ATSAM4CMS8C | ATSAM4C8x internal | 0E0000FF | 0 | 0 | 0 | 4BA00477 | 1000000 | 20000000 | 20000
Atmel | ATSAM4CMS16C | ATSAM4C16x internal | 0E0000FF | 0 | 0 | 0 | 4BA00477 | 1000000 | 20000000 | 20000
Atmel | ATSAM4CMS32C | ATSAM4C32x internal | 0E0000FF | 0 | 0 | 0 | 4BA00477 | 1000000 | 20000000 | 20000
Atmel | ATSAM4CMSP16C | ATSAM4C16x internal | 0E0000FF | 0 | 0 | 0 | 4BA00477 | 1000000 | 20000000 | 20000
Atmel | ATSAM4CP8B | ATSAM4C8x internal | 0E0000FF | 0 | 0 | 0 | 4BA00477 | 1000000 | 20000000 | 20000
Atmel | ATSAM4CP16B | ATSAM4C16x internal | 0E0000FF | 0 | 0 | 0 | 4BA00477 | 1000000 | 20000000 | 20000
Atmel | ATSAM4CP16C | ATSAM4C16x internal | 0E0000FF | 0 | 0 | 0 | 4BA00477 | 1000000 | 20000000 | 20000
Atmel | ATSAM4E8C | ATSAM4E8x internal | 0E0000FF | 0 | 0 | 0 | 4BA00477 | 400000 | 20000000 | 20000
Atmel | ATSAM4E8CB | ATSAM4E8x internal | 0E0000FF | 0 | 0 | 0 | 4BA00477 | 400000 | 20000000 | 20000
Atmel | ATSAM4E8E | ATSAM4E8x internal | 0E0000FF | 0 | 0 | 0 | 4BA00477 | 400000 | 20000000 | 20000
Atmel | ATSAM4E16C | ATSAM4E16x internal | 0E0000FF | 0 | 0 | 0 | 4BA00477 | 400000 | 20000000 | 20000
Atmel | ATSAM4E16CB | ATSAM4E16x internal | 0E0000FF | 0 | 0 | 0 | 4BA00477 | 400000 | 20000000 | 20000
Atmel | ATSAM4E16E | ATSAM4E16x internal | 0E0000FF | 0 | 0 | 0 | 4BA00477 | 400000 | 20000000 | 20000
Atmel | ATSAM4LC1A | ATSAM4Lx1xx internal | 0E0000FF | 0 | 0 | 0 | 2BA01477 | 0 | 20000000 | 4000
Atmel | ATSAM4LC1B | ATSAM4Lx1xx internal | 0E0000FF | 0 | 0 | 0 | 2BA01477 | 0 | 20000000 | 4000
Atmel | ATSAM4LC1C | ATSAM4Lx1xx internal | 0E0000FF | 0 | 0 | 0 | 2BA01477 | 0 | 20000000 | 4000
Atmel | ATSAM4LC2A | ATSAM4Lx2xx internal | 0E0000FF | 0 | 0 | 0 | 2BA01477 | 0 | 20000000 | 8000
Atmel | ATSAM4LC2B | ATSAM4Lx2xx internal | 0E0000FF | 0 | 0 | 0 | 2BA01477 | 0 | 20000000 | 8000
Atmel | ATSAM4LC2C | ATSAM4Lx2xx internal | 0E0000FF | 0 | 0 | 0 | 2BA01477 | 0 | 20000000 | 8000
Atmel | ATSAM4LC4A | ATSAM4Lx4xx internal | 0E0000FF | 0 | 0 | 0 | 2BA01477 | 0 | 20000000 | 8000
Atmel | ATSAM4LC4B | ATSAM4Lx4xx internal | 0E0000FF | 0 | 0 | 0 | 2BA01477 | 0 | 20000000 | 8000
Atmel | ATSAM4LC4C | ATSAM4Lx4xx internal | 0E0000FF | 0 | 0 | 0 | 2BA01477 | 0 | 20000000 | 8000
Atmel | ATSAM4LC8A | ATSAM4Lx8xx internal | 0E0000FF | 0 | 0 | 0 | 2BA01477 | 0 | 20000000 | 10000
Atmel | ATSAM4LC8B | ATSAM4Lx8xx internal | 0E0000FF | 0 | 0 | 0 | 2BA01477 | 0 | 20000000 | 10000
Atmel | ATSAM4LC8C | ATSAM4Lx8xx internal | 0E0000FF | 0 | 0 | 0 | 2BA01477 | 0 | 20000000 | 10000
Atmel | ATSAM4LS1A | ATSAM4Lx1xx internal | 0E0000FF | 0 | 0 | 0 | 2BA01477 | 0 | 20000000 | 4000
Atmel | ATSAM4LS1B | ATSAM4Lx1xx internal | 0E0000FF | 0 | 0 | 0 | 2BA01477 | 0 | 20000000 | 4000
Atmel | ATSAM4LS1C | ATSAM4Lx1xx internal | 0E0000FF | 0 | 0 | 0 | 2BA01477 | 0 | 20000000 | 4000
Atmel | ATSAM4LS2A | ATSAM4Lx2xx internal | 0E0000FF | 0 | 0 | 0 | 2BA01477 | 0 | 20000000 | 8000
Atmel | ATSAM4LS2B | ATSAM4Lx2xx internal | 0E0000FF | 0 | 0 | 0 | 2BA01477 | 0 | 20000000 | 8000
Atmel | ATSAM4LS2C | ATSAM4Lx2xx internal | 0E0000FF | 0 | 0 | 0 | 2BA01477 | 0 | 20000000 | 8000
Atmel | ATSAM4LS4A | ATSAM4Lx4xx internal | 0E0000FF | 0 | 0 | 0 | 2BA01477 | 0 | 20000000 | 8000
Atmel | ATSAM4LS4B | ATSAM4Lx4xx internal | 0E0000FF | 0 | 0 | 0 | 2BA01477 | 0 | 20000000 | 8000
Atmel | ATSAM4LS4C | ATSAM4Lx4xx internal | 0E0000FF | 0 | 0 | 0 | 2BA01477 | 0 | 20000000 | 8000
Atmel | ATSAM4LS8A | ATSAM4Lx8xx internal | 0E0000FF | 0 | 0 | 0 | 2BA01477 | 0 | 20000000 | 10000
Atmel | ATSAM4LS8B | ATSAM4Lx8xx internal | 0E0000FF | 0 | 0 | 0 | 2BA01477 | 0 | 20000000 | 10000
Atmel | ATSAM4LS8C | ATSAM4Lx8xx internal | 0E0000FF | 0 | 0 | 0 | 2BA01477 | 0 | 20000000 | 10000
Atmel | ATSAMC20E15 | ATSAMC20x15 internal | 060000FF | 0 | 0 | 0 | 0BC11477 | 0 | 20000000 | 1000
Atmel | ATSAMC20E16 | ATSAMC20x16 internal | 060000FF | 0 | 0 | 0 | 0BC11477 | 0 | 20000000 | 2000
Atmel | ATSAMC20E17 | ATSAMC20x17 internal | 060000FF | 0 | 0 | 0 | 0BC11477 | 0 | 20000000 | 4000
Atmel | ATSAMC20E18 | ATSAMC20x18 internal | 060000FF | 0 | 0 | 0 | 0BC11477 | 0 | 20000000 | 8000
Atmel | ATSAMC20G15 | ATSAMC20x15 internal | 060000FF | 0 | 0 | 0 | 0BC11477 | 0 | 20000000 | 1000
Atmel | ATSAMC20G16 | ATSAMC20x16 internal | 060000FF | 0 | 0 | 0 | 0BC11477 | 0 | 20000000 | 2000
Atmel | ATSAMC20G17 | ATSAMC20x17 internal | 060000FF | 0 | 0 | 0 | 0BC11477 | 0 | 20000000 | 4000
Atmel | ATSAMC20G18 | ATSAMC20x18 internal | 060000FF | 0 | 0 | 0 | 0BC11477 | 0 | 20000000 | 8000
Atmel | ATSAMC20J16 | ATSAMC20x16 internal | 060000FF | 0 | 0 | 0 | 0BC11477 | 0 | 20000000 | 2000
Atmel | ATSAMC20J17 | ATSAMC20x17 internal | 060000FF | 0 | 0 | 0 | 0BC11477 | 0 | 20000000 | 4000
Atmel | ATSAMC20J18 | ATSAMC20x18 internal | 060000FF | 0 | 0 | 0 | 0BC11477 | 0 | 20000000 | 8000
Atmel | ATSAMC21E15 | ATSAMC21x15 internal | 060000FF | 0 | 0 | 0 | 0BC11477 | 0 | 20000000 | 1000
Atmel | ATSAMC21E16 | ATSAMC21x16 internal | 060000FF | 0 | 0 | 0 | 0BC11477 | 0 | 20000000 | 2000
Atmel | ATSAMC21E17 | ATSAMC21x17 internal | 060000FF | 0 | 0 | 0 | 0BC11477 | 0 | 20000000 | 4000
Atmel | ATSAMC21E18 | ATSAMC21x18 internal | 060000FF | 0 | 0 | 0 | 0BC11477 | 0 | 20000000 | 8000
Atmel | ATSAMC21G15 | ATSAMC21x15 internal | 060000FF | 0 | 0 | 0 | 0BC11477 | 0 | 20000000 | 1000
Atmel | ATSAMC21G16 | ATSAMC21x16 internal | 060000FF | 0 | 0 | 0 | 0BC11477 | 0 | 20000000 | 2000
Atmel | ATSAMC21G17 | ATSAMC21x17 internal | 060000FF | 0 | 0 | 0 | 0BC11477 | 0 | 20000000 | 4000
Atmel | ATSAMC21G18 | ATSAMC21x18 internal | 060000FF | 0 | 0 | 0 | 0BC11477 | 0 | 20000000 | 8000
Atmel | ATSAMC21J16 | ATSAMC21x16 internal | 060000FF | 0 | 0 | 0 | 0BC11477 | 0 | 20000000 | 2000
Atmel | ATSAMC21J17 | ATSAMC21x17 internal | 060000FF | 0 | 0 | 0 | 0BC11477 | 0 | 20000000 | 4000
Atmel | ATSAMC21J18 | ATSAMC21x18 internal | 060000FF | 0 | 0 | 0 | 0BC11477 | 0 | 20000000 | 8000
Atmel | ATSAMD09C13 | ATSAMD09x13 internal | 060000FF | 0 | 0 | 0 | 0BC11477 | 0 | 20000000 | 1000
Atmel | ATSAMD09D14 | ATSAMD09x14 internal | 060000FF | 0 | 0 | 0 | 0BC11477 | 0 | 20000000 | 1000
Atmel | ATSAMD10C12 | ATSAMD10x12 internal | 060000FF | 0 | 0 | 0 | 0BC11477 | 0 | 20000000 | 1000
Atmel | ATSAMD10C13 | ATSAMD10x13 internal | 060000FF | 0 | 0 | 0 | 0BC11477 | 0 | 20000000 | 1000
Atmel | ATSAMD10C14 | ATSAMD10x14 internal | 060000FF | 0 | 0 | 0 | 0BC11477 | 0 | 20000000 | 1000
Atmel | ATSAMD10D12 | ATSAMD10x12 internal | 060000FF | 0 | 0 | 0 | 0BC11477 | 0 | 20000000 | 1000
Atmel | ATSAMD10D13 | ATSAMD10x13 internal | 060000FF | 0 | 0 | 0 | 0BC11477 | 0 | 20000000 | 1000
Atmel | ATSAMD10D14 | ATSAMD10x14 internal | 060000FF | 0 | 0 | 0 | 0BC11477 | 0 | 20000000 | 1000
Atmel | ATSAMD10D12AS | ATSAMD10x12 internal | 060000FF | 0 | 0 | 0 | 0BC11477 | 0 | 20000000 | 1000
Atmel | ATSAMD10D13AS | ATSAMD10x13 internal | 060000FF | 0 | 0 | 0 | 0BC11477 | 0 | 20000000 | 1000
Atmel | ATSAMD10D14AS | ATSAMD10x14 internal | 060000FF | 0 | 0 | 0 | 0BC11477 | 0 | 20000000 | 1000
Atmel | ATSAMD10D12AM | ATSAMD10x12 internal | 060000FF | 0 | 0 | 0 | 0BC11477 | 0 | 20000000 | 1000
Atmel | ATSAMD10D13AM | ATSAMD10x13 internal | 060000FF | 0 | 0 | 0 | 0BC11477 | 0 | 20000000 | 1000
Atmel | ATSAMD10D14AM | ATSAMD10x14 internal | 060000FF | 0 | 0 | 0 | 0BC11477 | 0 | 20000000 | 1000
Atmel | ATSAMD10D14AU | ATSAMD10x14 internal | 060000FF | 0 | 0 | 0 | 0BC11477 | 0 | 20000000 | 1000
Atmel | ATSAMD10E12 | ATSAMD10x12 internal | 060000FF | 0 | 0 | 0 | 0BC11477 | 0 | 20000000 | 1000
Atmel | ATSAMD10E13 | ATSAMD10x13 internal | 060000FF | 0 | 0 | 0 | 0BC11477 | 0 | 20000000 | 1000
Atmel | ATSAMD10E14 | ATSAMD10x14 internal | 060000FF | 0 | 0 | 0 | 0BC11477 | 0 | 20000000 | 1000
Atmel | ATSAMD11C12 | ATSAMD11x12 internal | 060000FF | 0 | 0 | 0 | 0BC11477 | 0 | 20000000 | 1000
Atmel | ATSAMD11C13 | ATSAMD11x13 internal | 060000FF | 0 | 0 | 0 | 0BC11477 | 0 | 20000000 | 1000
Atmel | ATSAMD11C14 | ATSAMD11x14 internal | 060000FF | 0 | 0 | 0 | 0BC11477 | 0 | 20000000 | 1000
Atmel | ATSAMD11D12 | ATSAMD11x12 internal | 060000FF | 0 | 0 | 0 | 0BC11477 | 0 | 20000000 | 1000
Atmel | ATSAMD11D13 | ATSAMD11x13 internal | 060000FF | 0 | 0 | 0 | 0BC11477 | 0 | 20000000 | 1000
Atmel | ATSAMD11D14 | ATSAMD11x14 internal | 060000FF | 0 | 0 | 0 | 0BC11477 | 0 | 20000000 | 1000
Atmel | ATSAMD11D14AS | ATSAMD11x14 internal | 060000FF | 0 | 0 | 0 | 0BC11477 | 0 | 20000000 | 1000
Atmel | ATSAMD11D14AM | ATSAMD11x14 internal | 060000FF | 0 | 0 | 0 | 0BC11477 | 0 | 20000000 | 1000
Atmel | ATSAMD11D14AU | ATSAMD11x14 internal | 060000FF | 0 | 0 | 0 | 0BC11477 | 0 | 20000000 | 1000
Atmel | ATSAMD11E12 | ATSAMD11x12 internal | 060000FF | 0 | 0 | 0 | 0BC11477 | 0 | 20000000 | 1000
Atmel | ATSAMD11E13 | ATSAMD11x13 internal | 060000FF | 0 | 0 | 0 | 0BC11477 | 0 | 20000000 | 1000
Atmel | ATSAMD11E14 | ATSAMD11x14 internal | 060000FF | 0 | 0 | 0 | 0BC11477 | 0 | 20000000 | 1000
Atmel | ATSAMD20E14 | ATSAMD20x14 internal | 060000FF | 0 | 0 | 0 | 0BC11477 | 0 | 20000000 | 800
Atmel | ATSAMD20E15 | ATSAMD20x15 internal | 060000FF | 0 | 0 | 0 | 0BC11477 | 0 | 20000000 | 1000
Atmel | ATSAMD20E16 | ATSAMD20x16 internal | 060000FF | 0 | 0 | 0 | 0BC11477 | 0 | 20000000 | 2000
Atmel | ATSAMD20E17 | ATSAMD20x17 internal | 060000FF | 0 | 0 | 0 | 0BC11477 | 0 | 20000000 | 4000
Atmel | ATSAMD20G14 | ATSAMD20x14 internal | 060000FF | 0 | 0 | 0 | 0BC11477 | 0 | 20000000 | 800
Atmel | ATSAMD20G15 | ATSAMD20x15 internal | 060000FF | 0 | 0 | 0 | 0BC11477 | 0 | 20000000 | 1000
Atmel | ATSAMD20G16 | ATSAMD20x16 internal | 060000FF | 0 | 0 | 0 | 0BC11477 | 0 | 20000000 | 2000
Atmel | ATSAMD20G17 | ATSAMD20x17 internal | 060000FF | 0 | 0 | 0 | 0BC11477 | 0 | 20000000 | 4000
Atmel | ATSAMD20G18 | ATSAMD20x18 internal | 060000FF | 0 | 0 | 0 | 0BC11477 | 0 | 20000000 | 8000
Atmel | ATSAMD20J14 | ATSAMD20x14 internal | 060000FF | 0 | 0 | 0 | 0BC11477 | 0 | 20000000 | 800
Atmel | ATSAMD20J15 | ATSAMD20x15 internal | 060000FF | 0 | 0 | 0 | 0BC11477 | 0 | 20000000 | 1000
Atmel | ATSAMD20J16 | ATSAMD20x16 internal | 060000FF | 0 | 0 | 0 | 0BC11477 | 0 | 20000000 | 2000
Atmel | ATSAMD20J17 | ATSAMD20x17 internal | 060000FF | 0 | 0 | 0 | 0BC11477 | 0 | 20000000 | 4000
Atmel | ATSAMD20J18 | ATSAMD20x18 internal | 060000FF | 0 | 0 | 0 | 0BC11477 | 0 | 20000000 | 8000
Atmel | ATSAMD21E14 | ATSAMD21x14 internal | 060000FF | 0 | 0 | 0 | 0BC11477 | 0 | 20000000 | 0800
Atmel | ATSAMD21E15 | ATSAMD21x15 internal | 060000FF | 0 | 0 | 0 | 0BC11477 | 0 | 20000000 | 1000
Atmel | ATSAMD21E16 | ATSAMD21x16 internal | 060000FF | 0 | 0 | 0 | 0BC11477 | 0 | 20000000 | 2000
Atmel | ATSAMD21E17 | ATSAMD21x17 internal | 060000FF | 0 | 0 | 0 | 0BC11477 | 0 | 20000000 | 4000
Atmel | ATSAMD21E18 | ATSAMD21x18 internal | 060000FF | 0 | 0 | 0 | 0BC11477 | 0 | 20000000 | 8000
Atmel | ATSAMD21G14 | ATSAMD21x14 internal | 060000FF | 0 | 0 | 0 | 0BC11477 | 0 | 20000000 | 0800
Atmel | ATSAMD21G15 | ATSAMD21x15 internal | 060000FF | 0 | 0 | 0 | 0BC11477 | 0 | 20000000 | 1000
Atmel | ATSAMD21G16 | ATSAMD21x16 internal | 060000FF | 0 | 0 | 0 | 0BC11477 | 0 | 20000000 | 2000
Atmel | ATSAMD21G17 | ATSAMD21x17 internal | 060000FF | 0 | 0 | 0 | 0BC11477 | 0 | 20000000 | 4000
Atmel | ATSAMD21G18 | ATSAMD21x18 internal | 060000FF | 0 | 0 | 0 | 0BC11477 | 0 | 20000000 | 8000
Atmel | ATSAMD21J14 | ATSAMD21x14 internal | 060000FF | 0 | 0 | 0 | 0BC11477 | 0 | 20000000 | 0800
Atmel | ATSAMD21J15 | ATSAMD21x15 internal | 060000FF | 0 | 0 | 0 | 0BC11477 | 0 | 20000000 | 1000
Atmel | ATSAMD21J16 | ATSAMD21x16 internal | 060000FF | 0 | 0 | 0 | 0BC11477 | 0 | 20000000 | 2000
Atmel | ATSAMD21J17 | ATSAMD21x17 internal | 060000FF | 0 | 0 | 0 | 0BC11477 | 0 | 20000000 | 4000
Atmel | ATSAMD21J18 | ATSAMD21x18 internal | 060000FF | 0 | 0 | 0 | 0BC11477 | 0 | 20000000 | 8000
Atmel | ATSAMDA1E14 | ATSAMDA1x14 internal | 060000FF | 0 | 0 | 0 | 0BC11477 | 0 | 20000000 | 800
Atmel | ATSAMDA1E15 | ATSAMDA1x15 internal | 060000FF | 0 | 0 | 0 | 0BC11477 | 0 | 20000000 | 1000
Atmel | ATSAMDA1E16 | ATSAMDA1x16 internal | 060000FF | 0 | 0 | 0 | 0BC11477 | 0 | 20000000 | 2000
Atmel | ATSAMDA1G14 | ATSAMDA1x14 internal | 060000FF | 0 | 0 | 0 | 0BC11477 | 0 | 20000000 | 800
Atmel | ATSAMDA1G15 | ATSAMDA1x15 internal | 060000FF | 0 | 0 | 0 | 0BC11477 | 0 | 20000000 | 1000
Atmel | ATSAMDA1G16 | ATSAMDA1x16 internal | 060000FF | 0 | 0 | 0 | 0BC11477 | 0 | 20000000 | 2000
Atmel | ATSAMDA1J14 | ATSAMDA1x14 internal | 060000FF | 0 | 0 | 0 | 0BC11477 | 0 | 20000000 | 800
Atmel | ATSAMDA1J15 | ATSAMDA1x15 internal | 060000FF | 0 | 0 | 0 | 0BC11477 | 0 | 20000000 | 1000
Atmel | ATSAMDA1J16 | ATSAMDA1x16 internal | 060000FF | 0 | 0 | 0 | 0BC11477 | 0 | 20000000 | 2000
Atmel | ATSAME70J19 | ATSAME70x19 internal | 0E0100FF | 0 | 0 | 0 | 0BD11477 | 400000 | 20400000 | 40000
Atmel | ATSAME70J20 | ATSAME70x20 internal | 0E0100FF | 0 | 0 | 0 | 0BD11477 | 400000 | 20400000 | 60000
Atmel | ATSAME70J21 | ATSAME70x21 internal | 0E0100FF | 0 | 0 | 0 | 0BD11477 | 400000 | 20400000 | 60000
Atmel | ATSAME70N19 | ATSAME70x19 internal | 0E0100FF | 0 | 0 | 0 | 0BD11477 | 400000 | 20400000 | 40000
Atmel | ATSAME70N20 | ATSAME70x20 internal | 0E0100FF | 0 | 0 | 0 | 0BD11477 | 400000 | 20400000 | 60000
Atmel | ATSAME70N21 | ATSAME70x21 internal | 0E0100FF | 0 | 0 | 0 | 0BD11477 | 400000 | 20400000 | 60000
Atmel | ATSAME70Q19 | ATSAME70x19 internal | 0E0100FF | 0 | 0 | 0 | 0BD11477 | 400000 | 20400000 | 40000
Atmel | ATSAME70Q20 | ATSAME70x20 internal | 0E0100FF | 0 | 0 | 0 | 0BD11477 | 400000 | 20400000 | 60000
Atmel | ATSAME70Q21 | ATSAME70x21 internal | 0E0100FF | 0 | 0 | 0 | 0BD11477 | 400000 | 20400000 | 60000
Atmel | ATSAMG51G18 | ATSAMG51G18 internal | 0E0000FF | 0 | 0 | 0 | 4BA00477 | 400000 | 20000000 | 10000
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

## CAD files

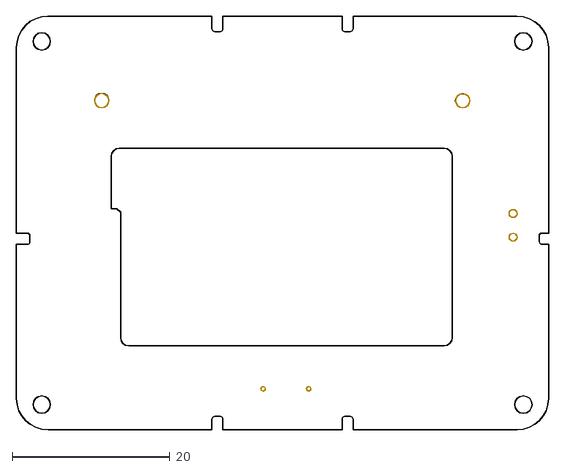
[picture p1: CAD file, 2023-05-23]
Design Files in Wio Terminal Wiki/Wio Terminal Chassis Battery/Wio-Terminal-Chassis-Battery.dxf
67.4 x 52.4

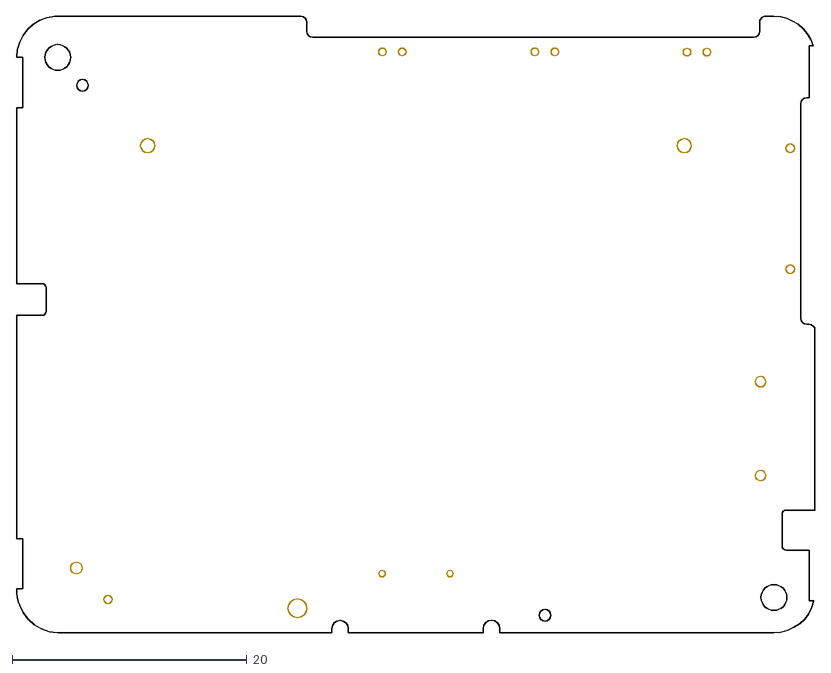
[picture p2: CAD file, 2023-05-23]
Design Files in Wio Terminal Wiki/Wio-Terminal/Wio-Terminal-PCB-V3.0.dxf
68.1 x 52.5

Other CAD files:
Design Files in Wio Terminal Wiki/Wio Terminal Enclosure Dimensions - Back/Wio-Terminal-Main-Back-V3.0-White-72x57x7.1mm.dxf
Design Files in Wio Terminal Wiki/Wio Terminal Enclosure Dimensions - Front/Wio-Terminal-Main-V3.0-White-72x57x10.4mm.dxf

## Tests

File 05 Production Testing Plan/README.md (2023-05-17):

# Wio Terminal Testplan

## 1. Flash Bootloader

### Firmware flash tool

[J-Link BASE Debug Probe](https://www.segger.com/products/debug-probes/j-link/models/j-link-base/)

 

## Wio Terminal port for program firmware

|No. |JLink |Wio Terminal |
| - | - | - |
|1 |Pin-1 |VTref |J7-6 |VCC3V3\_MCU |
|2 |Pin-7 |SWDIO |J7-2 |SWDIO |
|3 |Pin-9 |SWCLK |J7-1 |SWDCLK |
|4 |Pin-12 |GND |J7-5 |GND |

 

### Flash Script

```
@ECHO OFF
ECHO start to auto processing and exit
cd bootloader_upload_script_samd51
JFlash.exe -openprjDefault.jflash -openbootloader-wio_terminal-v3.7.0-79-gd73dd64.bin -auto -exit
IF ERRORLEVEL 1 goto ERROR
goto END

:ERROR
ECHO J-Flash program Error!!
cd ..
pause

:END
```

[bootloader_upload_script_samd51](https://github.com/MatthewJeffson/OSHW-WioTerminal/tree/main/05%20Production%20Testing%20Plan/bootloader_upload_script_samd51)

## 2. Flash test firmware

After flash the bootloader, connect Wio Terminal 's type C port to PC. Flash test firmware to Wio Terminal.

### Flash Script 

```
cd firmware_upload_script_usb
python2 0.testcode_flash.py 6
python2 1.ReceiveSerial.py
cd..
```

[firmware_upload_script_usb](https://github.com/MatthewJeffson/OSHW-WioTerminal/tree/main/05%20Production%20Testing%20Plan/firmware_upload_script_usb)

## 3. Function test

### a. Screen Test



### b. Function Test

Hardware connection when testing-fpc connector



Hardware connection when testing-Raspberry Pi Header





## 4. Flash End User Firmware

After complete the function test, flash the end user firmware to Wio Terminal 

### Flash Script 

```
echo %time%
cd ambd_flash_tool
:ambd_flash_tool.exe flash
python ambd_flash_tool.py erase
if %errorlevel% NEQ 0 goto error

timeout /t 1
python ambd_flash_tool.py flash
if %errorlevel% NEQ 0 goto error

timeout /t 2
cd ..
echo %time%
cd firmware_upload_script_usb
python2 0.testcode_flash.py 2
cd..
pause

:error
echo command failed
pause
```

[ambd_flash_tool](https://github.com/MatthewJeffson/OSHW-WioTerminal/tree/main/05%20Production%20Testing%20Plan/ambd_flash_tool)

After flash the firware, the screen will show as below



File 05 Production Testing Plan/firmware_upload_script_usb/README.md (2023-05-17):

These are firmware files for the Wio Terminal development board, and here are the descriptions after each file name represent different versions and functions of the firmware:

1. F4_WioTermianal_final_all.ino.bin: Test firmware that includes all functions.
2. F3_WioTerminal_fianl_no_bt.bin: Test firmware that does not include Bluetooth functionality.
3. F2_firmware_for_enduser.bin: Firmware for end users.
4. F1_bootloader_unlocked.ino.bin: Firmware that unlocks the bootloader and allows firmware to be burned.

On top of these firmware versions, there are also versions that have added new test steps or fixed some issues:

5. F4_WioTermianal_final_all.ino_v2.bin: Added test steps for whether the module is calibrated, including reading E-Fuse content and determining whether MAC address is written.
6. F3_WioTerminal_fianl_no_bt_v2.bin: Added test steps for whether calibration is performed, without Bluetooth functionality.
7. F4_WioTermianal_final_all.ino_v3.bin: Fixed issues in Pi Header GPIO test by adding 1 to the array count.
8. F3_WioTerminal_fianl_no_bt_v3.bin: Version without Bluetooth functionality, corresponding to F4_WioTermianal_final_all.ino_v3.bin.

In addition, there are versions marked with dates:

9. F3_WioterminalTestCode20200529.bin: RTL8720DN module firmware updated on May 29, 2020, for test firmware.
10. F3_WioterminalTestCode20200620.bin: Test firmware that added three switch function tests before welding the screen on June 20, 2020.
11. F3_WioterminalTestCode20200624.bin: Test firmware that added MP mode confirmation for calibration and WiFi scan on June 24, 2020.

Finally, there is a firmware dedicated to debugging:

12. F4_wifi_scan.ino.bin: Test firmware that added WiFi scan testing on July 8, 2022, only for debugging purposes.

Additionally, WioTerminalDebug.ino.bin is a firmware for manually confirming module functionality. It includes operations such as setting the module to MP mode, reading module E-Fuse data, instructing the module to scan WiFi, setting the module to normal mode, scanning WiFi in SPI mode, and reading module firmware version in SPI mode.

P 2 0 --> Set the module to MP mode
P 2 1 --> Read module E-Fuse data through the serial port
P 2 2 --> Instruct the module to scan WiFi through the serial port
P 3 0 --> Set the module to normal mode
P 4 --> Scan WiFi in SPI mode

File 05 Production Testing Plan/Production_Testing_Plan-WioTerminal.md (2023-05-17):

# Wio Terminal Testplan

## 1. Flash Bootloader

### Firmware flash tool

[J-Link BASE Debug Probe](https://www.segger.com/products/debug-probes/j-link/models/j-link-base/)

 

## Wio Terminal port for program firmware

|No. |JLink |Wio Terminal |
| - | - | - |
|1 |Pin-1 |VTref |J7-6 |VCC3V3\_MCU |
|2 |Pin-7 |SWDIO |J7-2 |SWDIO |
|3 |Pin-9 |SWCLK |J7-1 |SWDCLK |
|4 |Pin-12 |GND |J7-5 |GND |

 

### Flash Script

```
@ECHO OFF
ECHO start to auto processing and exit
cd bootloader_upload_script_samd51
JFlash.exe -openprjDefault.jflash -openbootloader-wio_terminal-v3.7.0-79-gd73dd64.bin -auto -exit
IF ERRORLEVEL 1 goto ERROR
goto END

:ERROR
ECHO J-Flash program Error!!
cd ..
pause

:END
```

[bootloader_upload_script_samd51.zip](https://github.com/MatthewJeffson/OSHW-WioTerminal/tree/main/05%20Production%20Testing%20Plan/bootloader_upload_script_samd51)

## 2. Flash test firmware

After flash the bootloader, connect Wio Terminal 's type C port to PC. Flash test firmware to Wio Terminal.

### Flash Script 

```
cd firmware_upload_script_usb
python2 0.testcode_flash.py 6
python2 1.ReceiveSerial.py
cd..
```

[firmware_upload_script_usb.zip](https://github.com/MatthewJeffson/OSHW-WioTerminal/tree/main/05%20Production%20Testing%20Plan/firmware_upload_script_usb)

## 3. Function test

### a. Screen Test



### b. Function Test

Hardware connection when testing-fpc connector



Hardware connection when testing-Raspberry Pi Header





## 4. Flash End User Firmware

After complete the function test, flash the end user firmware to Wio Terminal 

### Flash Script 

```
echo %time%
cd ambd_flash_tool
:ambd_flash_tool.exe flash
python ambd_flash_tool.py erase
if %errorlevel% NEQ 0 goto error

timeout /t 1
python ambd_flash_tool.py flash
if %errorlevel% NEQ 0 goto error

timeout /t 2
cd ..
echo %time%
cd firmware_upload_script_usb
python2 0.testcode_flash.py 2
cd..
pause

:error
echo command failed
pause
```

[ambd_flash_tool.zip](https://drive.weixin.qq.com/s?k=AGEAZwfLABEfeMBB1KAb8ACQYAAEM)

After flash the firware, the screen will show as below



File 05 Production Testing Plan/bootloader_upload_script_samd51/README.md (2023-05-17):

bootloader-wio_terminal-v3.7.0-79-gd73dd64.bin	--Wio Terminal SADM51 Bootloader

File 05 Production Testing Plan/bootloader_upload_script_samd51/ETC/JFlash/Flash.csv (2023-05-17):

Manufacturer | Name | Id16 | Id8 | Internal | Algo | AlgoVar | BusWidth | SupportsSectorErase | SupportsChipErase | ZeroProgram | SupportsSoftLock | SoftLockAreaType(0:Sector,1:Chip) | SoftUnlockAreaType | SupportsHardLock | HardLockAreaType | SupportsHardUnlock | HardUnlockAreaType | SoftLockResetState(0:Remember,1:ON,2:OFF) | SupportsSecure | SupportsUnsecure | Sectors
Atmel | AC33M8128 internal | 0 | 0 | 1 | 82 | 0 | 32 | 1 | 1 | 0 | 0 | 0 | 0 | 0 | 0 | 0 | 0 | 0 | 1 | 0 | 80[1024];
Actel | A2FxxxM3E internal | 0 | 0 | 1 | 76 | 0 | 32 | 1 | 0 | 0 | 0 | 0 | 0 | 0 | 0 | 0 | 0 | 0 | 0 | 0 | 80[1024];
Actel | A2FxxxM3F internal | 0 | 0 | 1 | 76 | 0 | 32 | 1 | 0 | 0 | 0 | 0 | 0 | 0 | 0 | 0 | 0 | 0 | 0 | 0 | 80[2048];
Actel | A2FxxxM3G internal | 0 | 0 | 1 | 76 | 0 | 32 | 1 | 0 | 0 | 0 | 0 | 0 | 0 | 0 | 0 | 0 | 0 | 0 | 0 | 80[4096];
active-semi | PAC52xx internal | 0 | 0 | 1 | 98 | 0 | 32 | 1 | 0 | 0 | 0 | 0 | 0 | 0 | 0 | 0 | 0 | 0 | 0 | 0 | 400[32];
AmbiqMicro | APOLLO512 internal | 0 | 0 | 1 | 94 | 0 | 32 | 1 | 1 | 0 | 0 | 0 | 0 | 0 | 0 | 0 | 0 | 0 | 0 | 0 | 800[256];
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

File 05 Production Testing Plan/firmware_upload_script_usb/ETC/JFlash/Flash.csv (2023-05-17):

Manufacturer | Name | Id16 | Id8 | Internal | Algo | AlgoVar | BusWidth | SupportsSectorErase | SupportsChipErase | ZeroProgram | SupportsSoftLock | SoftLockAreaType(0:Sector,1:Chip) | SoftUnlockAreaType | SupportsHardLock | HardLockAreaType | SupportsHardUnlock | HardUnlockAreaType | SoftLockResetState(0:Remember,1:ON,2:OFF) | SupportsSecure | SupportsUnsecure | Sectors
Actel | A2FxxxM3E internal | 0 | 0 | 1 | 76 | 0 | 32 | 1 | 0 | 0 | 0 | 0 | 0 | 0 | 0 | 0 | 0 | 0 | 0 | 0 | 80[1024];
Actel | A2FxxxM3F internal | 0 | 0 | 1 | 76 | 0 | 32 | 1 | 0 | 0 | 0 | 0 | 0 | 0 | 0 | 0 | 0 | 0 | 0 | 0 | 80[2048];
Actel | A2FxxxM3G internal | 0 | 0 | 1 | 76 | 0 | 32 | 1 | 0 | 0 | 0 | 0 | 0 | 0 | 0 | 0 | 0 | 0 | 0 | 0 | 80[4096];
AMD | Am29DL161DB | 12239 | 10039 | 0 | 1 | 0 | 16 | 1 | 0 | 0 | 0 | 0 | 0 | 0 | 0 | 0 | 0 | 0 | 0 | 0 | 2000[8]; 10000[31];
AMD | Am29DL161DT | 12236 | 10036 | 0 | 1 | 0 | 16 | 1 | 0 | 0 | 0 | 0 | 0 | 0 | 0 | 0 | 0 | 0 | 0 | 0 | 10000[31]; 2000[8];
AMD | Am29DL162DB | 01222E | 01002E | 0 | 1 | 0 | 16 | 1 | 0 | 0 | 0 | 0 | 0 | 0 | 0 | 0 | 0 | 0 | 0 | 0 | 2000[8]; 10000[3]; 10000[28];
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

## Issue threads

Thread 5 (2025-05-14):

Add Cross-Platform Support for amebad_image_tool on armv7l/arm64 (Python or Precompiled)

Electro-Gamma, 2025-05-14:
**Is your feature request related to a problem? Please describe.**
The `amebad_image_tool` under `Production Testing Plan/ambd_flash_tool/tool/linux/` is currently provided only as an x86/x64 binary. This prevents its use on popular ARM-based development platforms like Raspberry Pi (armv7l or arm64).

**Describe the solution you'd like**
Please provide:
1. A cross-platform implementation of `amebad_image_tool` written in Python, OR
2. Precompiled binaries for armv7l and arm64 architectures.

This would allow developers using ARM-based devices to fully utilize the Ameba SDK, including flashing and testing utilities.

**Describe alternatives you've considered**
- Emulating x86 on ARM devices, which is inefficient.
- Attempting to reverse-engineer or port the tool manually.

**Additional context**
Cross-platform flashing support is essential for automated deployment and testing environments, especially when using single-board computers like Raspberry Pi in production or prototyping workflows.

Electro-Gamma, 2025-05-29:
??

Closed 2025-06-05.

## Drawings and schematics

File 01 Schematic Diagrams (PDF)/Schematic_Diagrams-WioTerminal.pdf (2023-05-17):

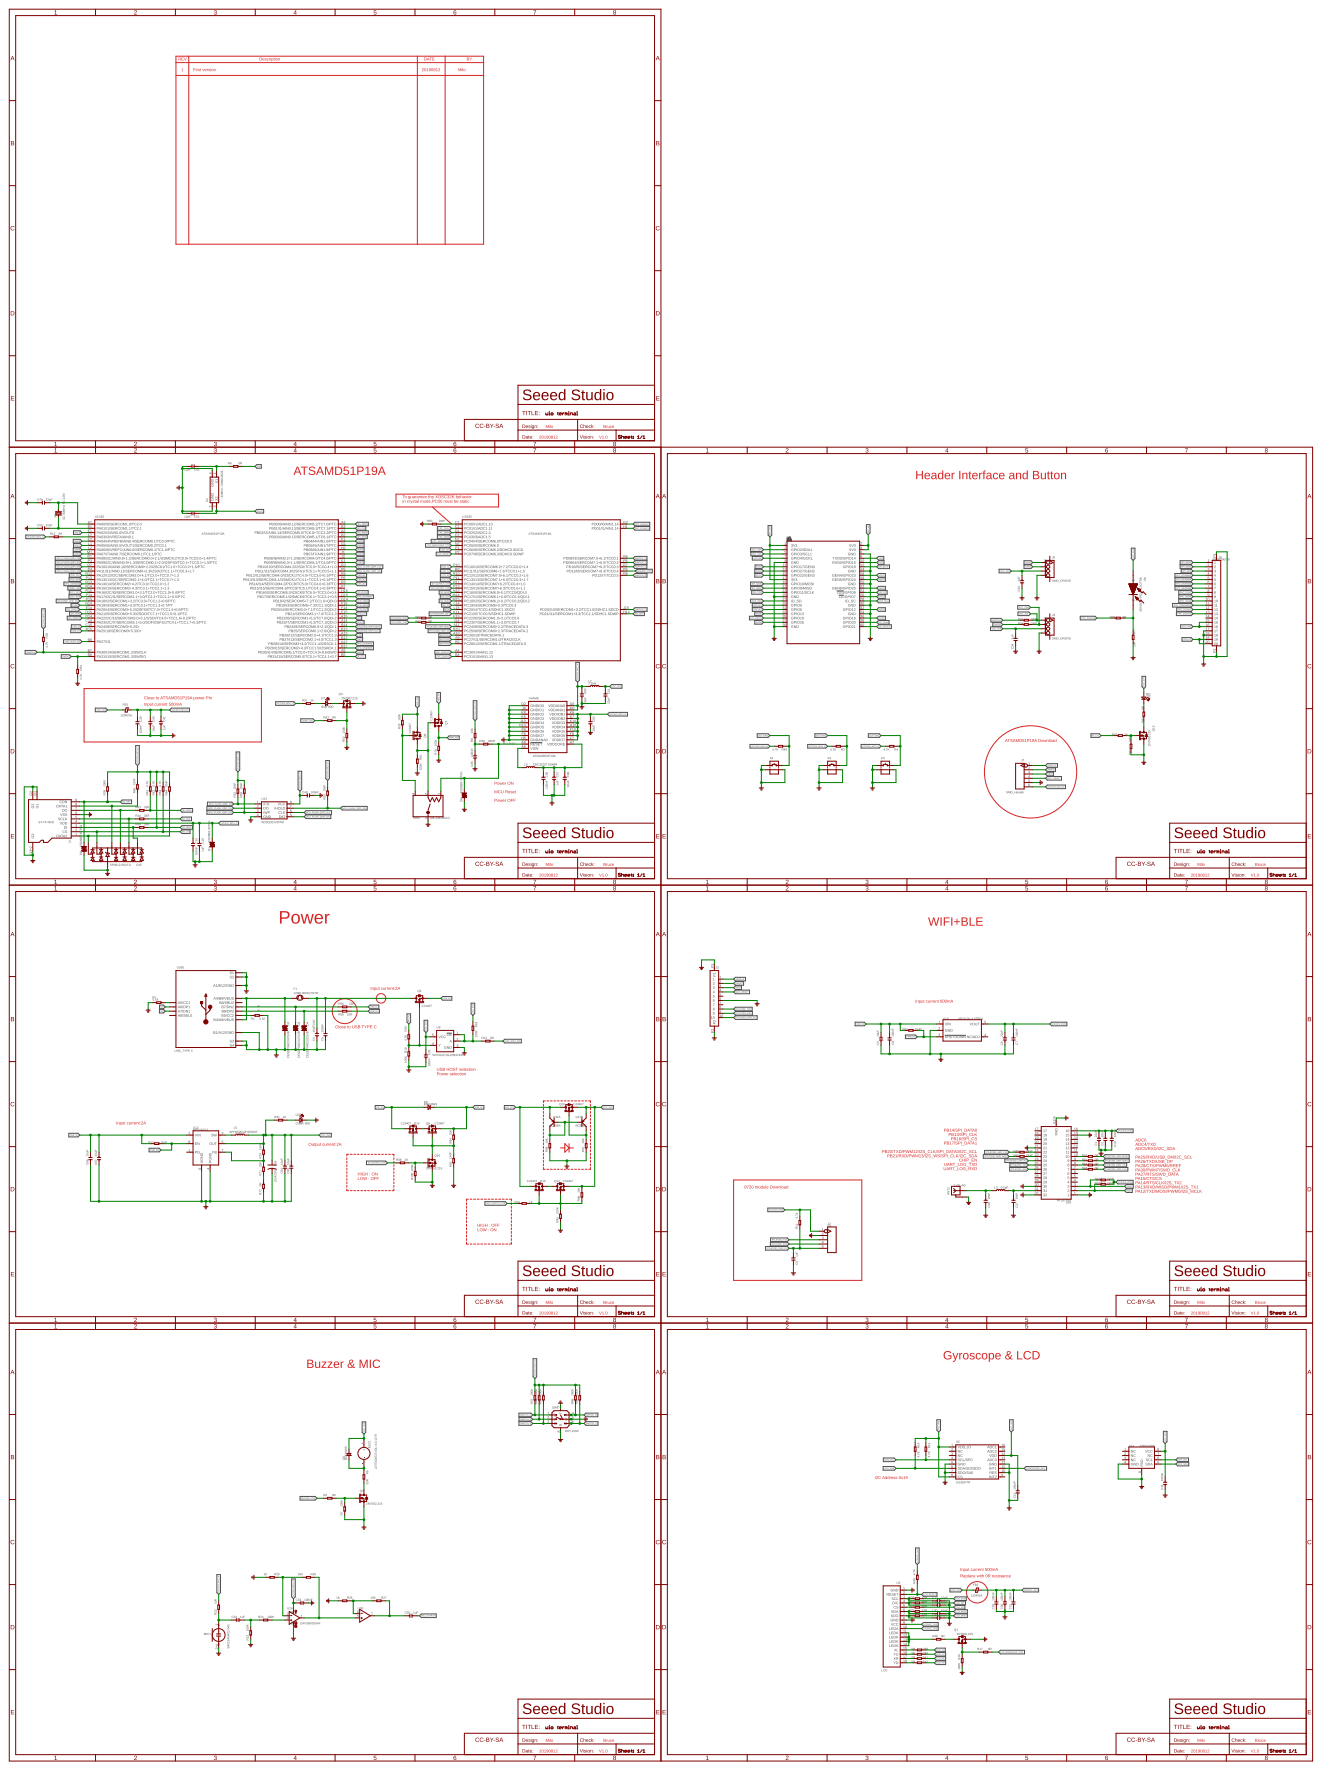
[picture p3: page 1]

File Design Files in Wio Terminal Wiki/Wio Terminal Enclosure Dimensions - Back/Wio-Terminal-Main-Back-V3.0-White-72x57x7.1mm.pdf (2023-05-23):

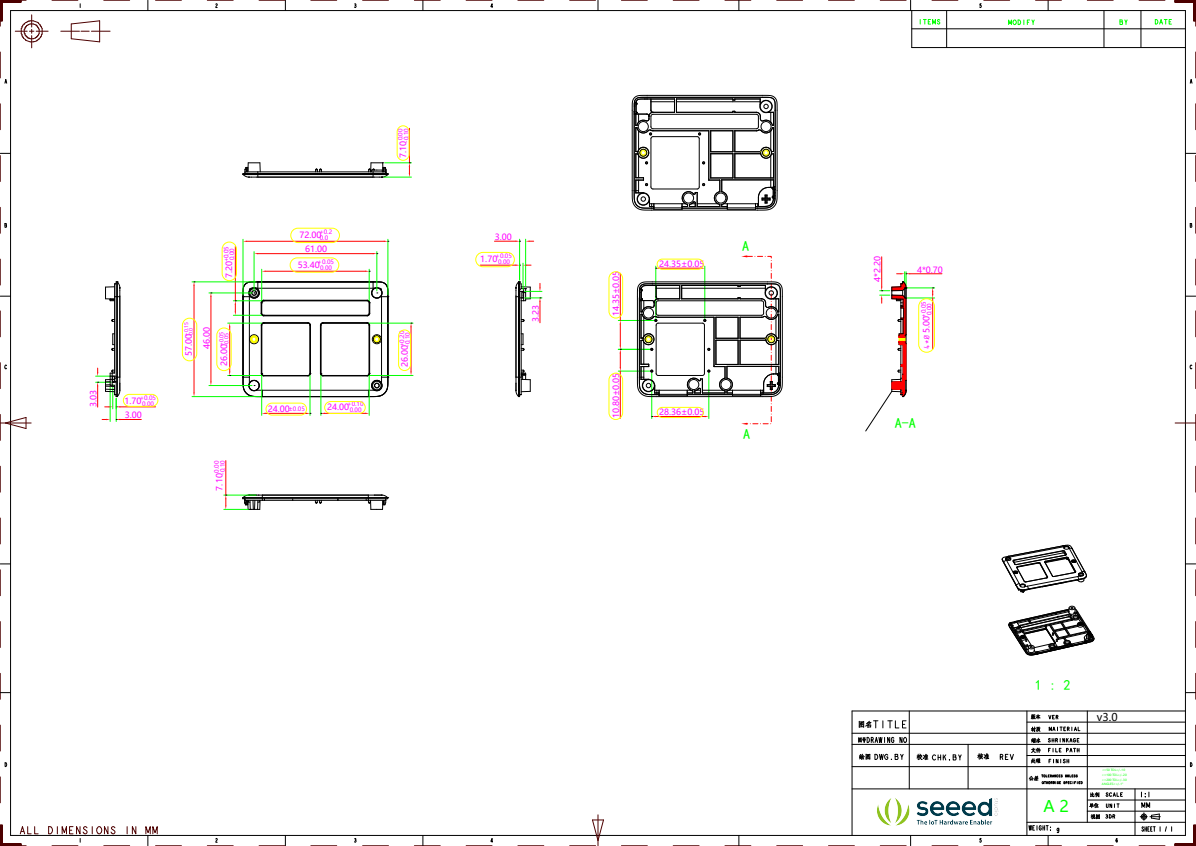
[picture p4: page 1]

<=50 TOL+/-.10 <=100 TOL+/-.20 <=200 TOL+/-.30 ANGLES=+/-1°
A 2

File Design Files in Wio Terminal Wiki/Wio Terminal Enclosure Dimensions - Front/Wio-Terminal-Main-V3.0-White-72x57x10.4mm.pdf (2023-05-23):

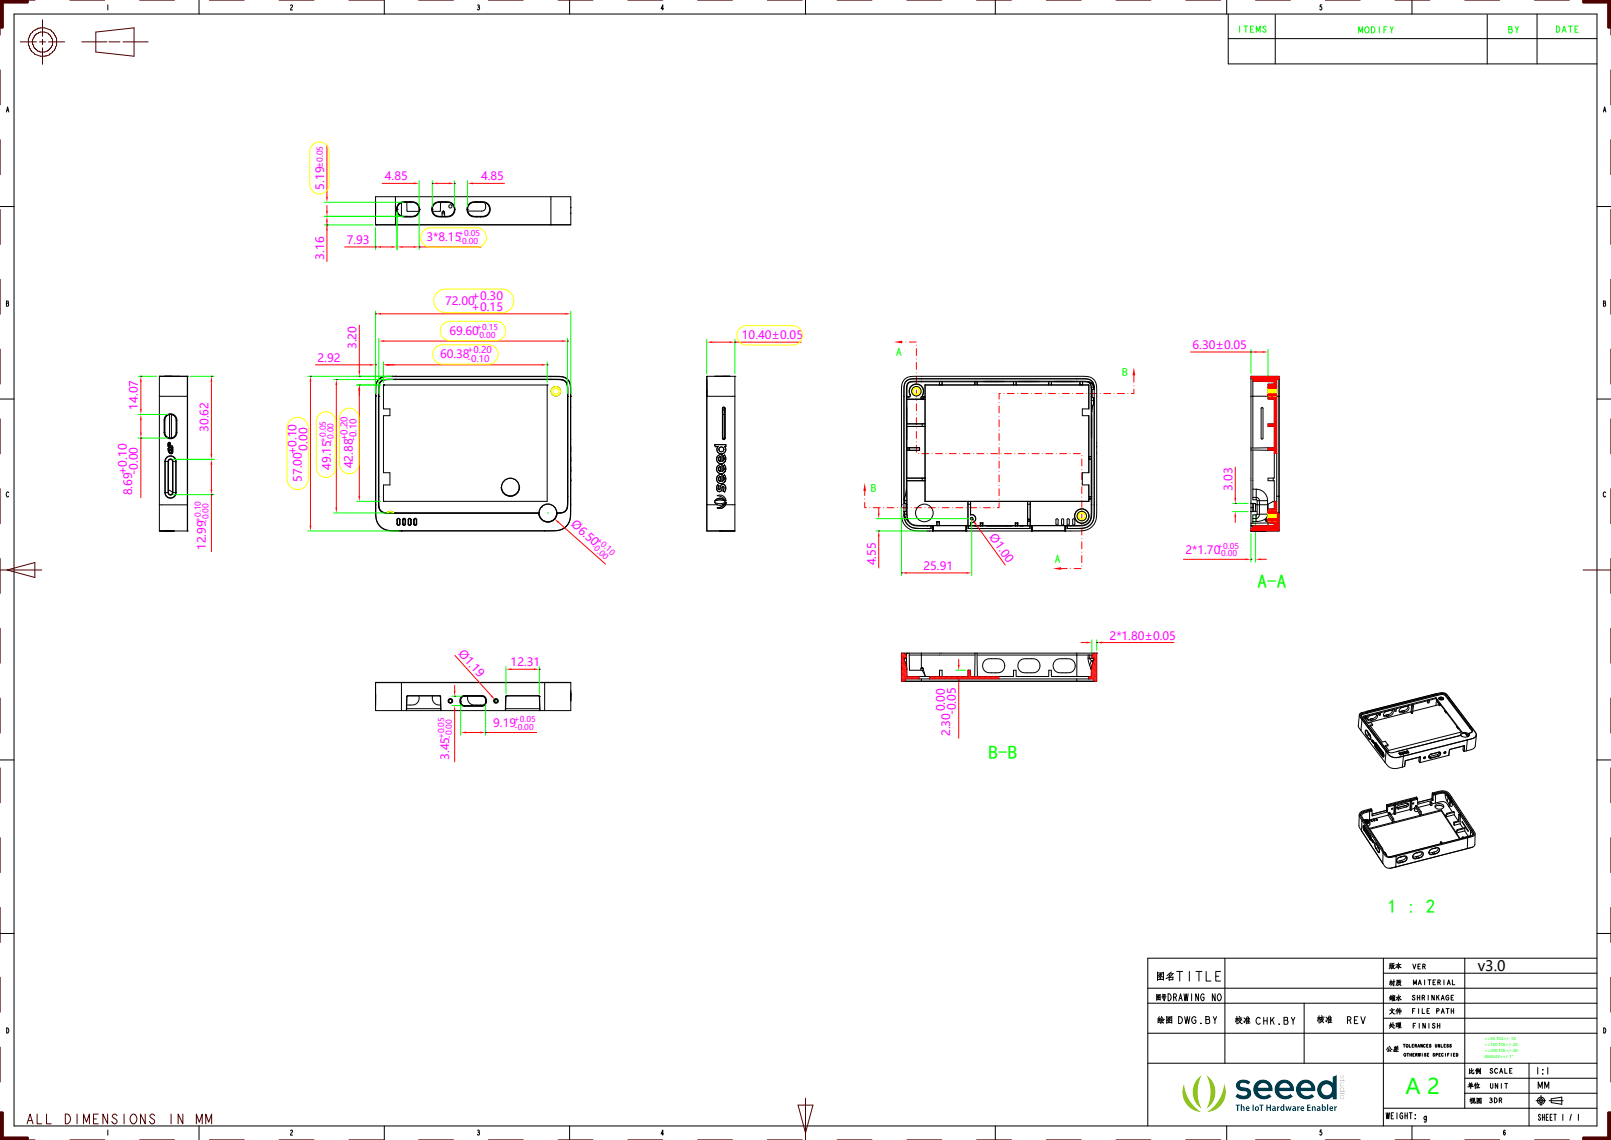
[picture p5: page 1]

<=50 TOL+/-.10 <=100 TOL+/-.20 <=200 TOL+/-.30 ANGLES=+/-1°
A 2

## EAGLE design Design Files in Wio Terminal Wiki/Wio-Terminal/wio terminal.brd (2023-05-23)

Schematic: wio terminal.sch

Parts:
ANT2: 2.4G+5G; ANT2P-AMEBA-D-MODULE
BUZ1: LET5020CS-03L-4.0-12-R; BZ3-SMD-5.0X5.0X2.5MM
C1, C6: 22uF; C0603
C2, C3: 10uF; C0603
C4: 10uF/10V; C0603
C5, C7, C8, C10, C11, C14, C15, C29, C30, C31, C32, C33, C35, C36, C39, C48: 100nF; C0402
C9, C16, C34, C37, C41, C53, C54, C55: 1uF; C0402
C12, C13, C42, C43: 10pF; C0402
C27, C28: DNP; C0402
C38, C40, C60, C61, C62, C64, C65, C66, C67: 10uF; C0402
C49, C50: 22pF; C0402
C51, C52: 12pF; C0402
C63: 22uF/10V; AVX-A
D1, D6, D8: ESD9B3.3ST5G; ESD-0402
D2, D3, D4: CESDP0402UC5VB; ESD-0402
D5, D9: B5819WS; SOD-323
D7: Blue 90D; LED-SIDE-VIEW-0603-RIGHT
D10: IR; LED-0603
D15: SP3012-06UTG; UDFN14-0.5-3.5X1.35X0.5MM
F1: 1206L300SLTHYR; F1206
FB2, FB3: 120R/2A; F0402
J1: ST-TF-003J; MICRO-SD9+4P-SMD-16.1X14.5X1.85MM
J2: DL; H5-SMD-2.0-TEST
J3: FPC-CONNECTOR-10PTOP''; FPC10-SMD-0.5-10.6X3.5X4.5MM
J4, J5: SMD_GROVE; HW4-SMD-2.0-90D
J6: XW05200-20; FPC20-SMD-0.5-90D
J7: SMD_Header; H6-SMD-2.0_TEST
K1, K2, K3: BUTTON-2+2P-TS-1073B; SW2+2P-3.45-4.8X2.5X1.8MM
L2: 2.2uH; L0805
L3: 0.5pF; L0402
L5: SPH252012H1R2MT; L2520
L6: CBC3225T100MR; L2520
LED1: Green 90D; LED-SIDE-VIEW-0603-RIGHT
MIC1: B4013AM422-042; MIC2-SMD-4X4MM
Q1, Q3, Q4, Q13, Q16: 2N7002,215; SOT-23
Q2, Q7, Q8, Q9, Q10, Q12, Q14, Q15: CJ3407; SOT-23
Q11: BC856S; SOT-363
R1, R2: 5.1K; R0402
R3, R4, R13, R14, R20, R38, R48, R49, R54, R61, R62, R63: 4.7K; R0402
R5, R8, R12, R17, R21, R39, R40, R41, R42, R46, R53, R66, R67, R68, R69, R72, R79, R81, R82, R83: 0R; R0402
R6, R35, R43, R44, R45, R57, R74, R75, R76: 33R; R0402
R7, R16, R18, R19, R23, R24, R36, R37, R84, R85, R86, R87, R91, R95, R100: 100K; R0402
R9, R22, R26, R27, R77, R94, R96, R97, R98: 10K; R0402
R10, R32, R33, R34, R50, R58, R59, R60, R64, R65, R73, R90, R93, R102, R103: DNP; R0402
R11: 4.7k; R0402
R25, R28, R31, R88, R99: 1K; R0402
R29, R52, R78, R80: 100k; R0402
R30: 330R; R0402
R47, R51: 1k; R0402
R55, R56: 22R; R0402
R70: 150K; R0402
R71: 33K; R0402
SW1: DHT-1500; SWITCH-2X3P
SW3: MK-13E03N-G; SW4-SMD-11.2X3.6MM
U1: ATSAMD51P19A; TFBGA120-0.5-8X8MM
U2: LMV358IDGKR; MSOP8-0.65-3X3MM
U3: RPI; H2X20-SMD-2.54-50.8X5MM-LONG
U4: LCD; LCM18-0.8-60.26X42.72X2.2MM
U5: LIS3DHTR; LGA16-0.5-3X3MM
U8: SENSOR-PD15-22C/TR8; SNR4-SMD-3.2X2.7MM
U9: SN74LVC1G125DCKR; SC-70-5
U10: RTL8720D; MODULE-32P-0.8-13X12MM-MOTHER
U11: ATECC608; UDFN8-0.5-2X3X0.5MM
U12: MP2161GJ; TSOT23-8
U13: AP2112K-3.3TRG1; SOT-23-5
U14: W25Q32JVZPIM; SOIC8-1.27-5.3X5.3MM
USB1: USB_TYPE C; USB2.0-TYPE-C
X2: 32.768KHz FC-12M; X2-SMD-L2.0X1.2X0.55MM
X4: 32MHz / 306010026; X4-SMD-3.2X2.5X0.7MM

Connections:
3V3_OUTPUT_CTR: R99.2, U1.P12 (PC15/I15/SERCOM7+6.3/TCC0.5+1.1)
5V_OUTPUT_CTR: R88.1, U1.R11 (PC14/I14/SERCOM7+6.2/TCC0.4+1.0)
A0/D0: J5.1, U1.J2 (PB08/I8/AIN0.2+1.0/SERCOM4.0/TC4.0/PTC), U3.13 (GPIO27/GEN2)
A1/D1: J5.2, U1.K1 (PB09/I9/AIN0.3+1.1/SERCOM4.1/TC4.0/PTC), U3.15 (GPIO22/GEN3)
A2/D2: U1.M1 (PA07/I7/AIN0.7/SERCOM0.1/TC1.1/PTC), U3.16 (GEN4/GPIO23)
A3/D3: U1.F1 (PB04/I4/AIN1.6/PTC), U3.18 (GEN5/GPIO24)
A4/D4: U1.G1 (PB05/I5/AIN1/7/PTC), U3.22 (GEN6/GPIO25)
A5/D5: U1.H2 (PB06/I6/AIN1.8/PTC), U3.32 (GPIO12)
A6/D6: U1.K2 (PA04/I4/VREFB/AIN0.4/SERCOM0.1/TC0.0/PTC), U3.33 (GPIO13)
A7/D7: U1.J1 (PB07/I7/AIN1.9/PTC), U3.36 (GPIO16)
A8/D8: U1.L2 (PA06/I6/VREFC/AIN0.6/SERCOM0.1/TC1.0/PTC), U3.37 (GPIO26)
BUTTON1: K1.2, R49.1, U1.A10 (PC26/I10/TRACEDATA.1)
BUTTON2: K2.2, R3.1, U1.A9 (PC27/I11/SERCOM1.0/TRACECLK)
BUTTON3: K3.2, R4.1, U1.B9 (PC28/I12/SERCOM1.1/TRACEDATA.0)
BUZZER_CTR: R5.1, U1.P9 (PD11/I6/SERCOM7+6.3/TCC0.4)
DAC0: U1.E1 (PA02/I2/AIN0.0/VOUT0), U3.11 (GPIO17/GEN0)
DAC1: U1.L1 (PA05/I5/AIN0.5/VOUT1/SERCOM0.2/TC0.1), U3.26 (!CE!/GPIO7)
DN: D3.1, R55.1, USB1.A7 (A7/DN1), USB1.B7 (B7/DN2)
DP: D4.1, R56.2, USB1.A6 (A6/DP1), USB1.B6 (B6/DP2)
FPC_D3/PWM3: J6.4, U1.A12 (PB28/I14/SEROM2+4.2/TCC1.4/I2SSCK.1)
FPC_D4/PWM4: J6.5, U1.G15 (PB17/SERCOM5.1/I2SMCK0/TC6.1+TCC3.1+0.5)
FPC_D5/PWM5: J6.6, U1.B11 (PB29/I15/SERCOM2+4.3/TCC1.5/I2SMCK.1)
FPC_D6/PWM6: J6.7, U1.R13 (PA14/I14/SERCOM2+4.2/TC3.0+TCC2.0+1.2)
FPC_D7/A7: J6.8, U1.C2 (PC01/I1/ADC1.11)
FPC_D8/A8: J6.9, U1.D1 (PC02/I2/ADC1.4)
FPC_D9/A9: J6.10, U1.E2 (PC03/I3/ADC1.5)
FPC_D10/PWM10: J6.11, U1.N1 (PC04/I4/SERCOM6.0/TCC0.0)
FPC_D11/A11: J6.12, U1.B4 (PC31/I15/AIN1.13)
FPC_D12/A12: J6.13, U1.G2 (PD00/I0/AIN1.14)
FPC_D13/A13: R79.2, U1.H1 (PD01/I1/AIN1.14)
GND: ANT2.1, C1.1, C2.1, C3.1, C4.1, C5.1, C6.1, C7.2, C8.2, C9.2, C10.2, C11.1, C12.2, C13.2, C14.1, C15.2, C16.2, C27.1, C28.1, C29.1, C30.1, C31.1, C32.2, C33.2, C35.2, C36.2, C37.2, C38.2, C39.2, C40.2, C41.2, C42.2, C43.2, C48.2, C49.1, C50.1, C51.2, C52.2, C53.2, C54.2, C60.2, C61.2, C62.2, C63.-, C64.1, C65.1, C66.1, C67.1, D1.1, D2.2, D3.2, D4.2, D6.1, D8.1, D15.5 (10), D15.10, J1.6 (VSS), J1.G1, J1.G2, J1.G3, J1.G4 (G3), J2.2, J3.6, J3.P1, J3.P2, J4.4, J5.4, J6.17, J6.18, J6.P1, J6.P2, J7.5, K1.1, K1.3 (S1), K1.4 (S2), K2.1, K2.3 (S1), K2.4 (S2), K3.1, K3.3 (S1), K3.4 (S2), LED1.2 (-), MIC1.2 (-), MIC1.3 (-), MIC1.4 (-), MIC1.5 (-), Q1.2 (S), Q3.2 (S), Q4.2 (S), Q13.2 (S), Q16.2 (S), R1.1, R2.1, R7.1, R16.2, R19.2, R23.2, R25.1, R28.1, R50.2, R52.1, R54.2, R72.1, R77.1, R78.1, R80.2, R91.2, R93.1, R95.1, R97.1, R98.1, R100.1, SW1.5, SW1.7, SW1.8, SW3.3, U1.D2 (GNDIO0), U1.F6 (GNDIO7), U1.F9 (GNDIO6), U1.G10 (GNDIO5), U1.H6 (GNDANA0), U1.J6 (GNDIO1), U1.J10 (GNDIO4), U1.K8 (GNDIO2), U1.K9 (GNDIO3), U2.4 (GND), U3.6 (GND), U3.9 (GND), U3.14 (GND), U3.20 (GND), U3.25 (GND), U3.30 (GND), U3.34 (GND), U3.39 (GND), U4.1 (GND), U4.8 (GND), U5.5 (GND), U5.7 (SDO/SA0), U5.10 (RES), U5.12 (GND), U9.3 (GND), U10.1, U10.15, U10.21, U10.30, U10.32, U10.51 (PAD), U10.54 (PAD), U10.60 (PAD), U10.61 (PAD), U11.4 (GND), U11.9 (PAD), U12.4 (PGND), U12.6 (AGND), U13.2 (GND), U14.4 (GND), USB1.A1_B12 (A1/B12/GND), USB1.B1_A12 (B1/A12/GND), USB1.S1, USB1.S2, USB1.S3, USB1.S4, USB1.S5 (S1), USB1.S6 (S2), X4.2 (GND), X4.4 (GND)
GPCLK0: U1.R5 (PB14/I14/SERCOM4.2/PCC8/TC5.0+TCC4.0+0.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), U3.7 (GPIO4/GCKL)
GPCLK1: U1.R4 (PB12/I12/SERCOM4.0/I2SCK1/TC4.0+TCC3.0+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), U3.29 (GPIO5)
GPCLK2: U1.P6 (PB13/I13/SERCOM4.1/I2SMCK1/TC4.1+TCC3.1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), U3.31 (GPIO6)
GYROSCOPE_INT1: U1.K14 (PC21/I5/TCC0.5/SDHC1.SDWP), U5.11 (INT1)
I2C0_SCL: R13.2, U1.R12 (PA12/I12/I2C/SERCOM2.0+4.1/TC2.0+TCC0.7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), U3.28 (ID_SC), U5.4 (SCL/SPC), U11.6 (SCL)
I2C0_SDA: R14.2, U1.P13 (PA13/I13/I2C/SERCOM2.1+4.0/TC2.1+TCC0.7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), U3.27 (ID_SD), U5.6 (SDA/SDI/SDO), U11.5 (SDA)
I2C1_SCL: J4.1, R33.1, U1.R15 (PA16/I2C/I0/SERCOM1.0+3.1/TC2.0+TCC1.0+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), U3.5 (GPIO3/SCL1)
I2C1_SDA: J4.2, R34.1, U1.P14 (PA17/I2C/I1/SERCOM1.1+3.0/TC2.1+TCC1.1+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), U3.3 (GPIO2/SDA1)
I2S_BLCK: U1.H15 (PB16/I0/SERCOM5.0/I2SCK0/TC6.0+TCC3.0+0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), U3.12 (GPIO18)
I2S_LRCLK: U1.E14 (PA20/I4/SERCOM3+5.2/I2SFS0/TC7.0+TCC1.4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), U3.35 (GPIO19)
I2S_SDIN: U1.D15 (PA21/I5/SERCOM3+5.3/I2SDO/TC7.1+TCC1.5+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), U3.38 (GPIO20)
I2S_SDOUT: U1.D14 (PA22/I2C/16/SERCOM3.0+5.1/I2SDI/TC4.0+T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), U3.40 (GPIO21)
IRQ0: R103.1, U1.L15 (PC20/I4/TCC0.4/SDHC1.SDCD), U10.2
IR_CTL: R47.2, U1.B5 (PB31/I15/SERCOM5.0/TC0.1+TCC4.1+0.7)
LCDVCC_3V3: C29.2, C30.2, C31.2, FB2.2, R48.2, U4.9 (VCC), U4.10 (LEDA)
LCD_BACKLIGHT_CTR: R17.2, U1.N2 (PC05/I5/SERCOM6.0)
LCD_CS: R74.2, U1.E15 (PB21/SERCOM3.1+7.0/TCC1.3)
LCD_D/C: R57.2, U1.P1 (PC06/I6/SERCOM6.2/SDHC0.SDCD)
LCD_MISO: R76.2, U1.G14 (PB18/I2/SERCOM5+7.2/TCC1.0+QDI.0)
LCD_MOSI: R75.2, U1.F15 (PB19/I3/SERCOM5+7.3/CC1.1/QDI.1)
LCD_RESET: R48.1, U1.P2 (PC07/I9/SERCOM6.3/SDHC0.SDWP), U4.2 (RESET)
LCD_SCK: R35.2, U1.F14 (PB20/I4/SERCOM3.0+7.1/TCC1.2/QDI.2)
LCD_XL: R39.1, U1.P10 (PC10/I10/SERCOM6.2+7.2/TCC0.0+1.4)
LCD_XR: R41.1, U1.R10 (PC12/I12/SERCOM7.0+6.1/TCC0.2+1.6)
LCD_YD: R42.1, U1.P11 (PC13/I13/SERCOM7.1+6.0/TCC0.3+1.7)
LCD_YU: R40.1, U1.R9 (PC11/I11/SERCOM6+7.3/TCC0.1+1.5)
MCU_FLASH_QSPI_CLK: U1.R3 (PB10/I10/SERCOM4.2/I2SDI/TC5.0+TCC0.4+1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), U14.6 (CLK)
MCU_FLASH_QSPI_CS: R32.1, U1.P5 (PB11/I11/SERCOM4.3/I2SFS1/TC5.1+TCC0.5+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), U14.1 (/CS)
MCU_FLASH_QSPI_IO0: U1.R1 (PA08/I2C/AIN0.8+1.2/SERCOM0.0+2.1/I2SMC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), U14.5 (DIO)
MCU_FLASH_QSPI_IO1: U1.P3 (PA09/I2C/I9/AIN0.9+1.3/SERCOM0.1+2.0/I2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), U14.2 (DO)
MCU_FLASH_QSPI_IO2: R58.1, U1.R2 (PA10/I10/AIN0.10/SERCOM0+2.2/I2SCK1/TC1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), U14.3 (/WP)
MCU_FLASH_QSPI_IO3: R59.1, U1.P4 (PA11/I11/AIN0.11/SERCOM0+2.3/I2SDO/TC1.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), U14.7 (/HOLD)
MCU_RESET: D6.2, J3.4, J7.4, R30.2, SW3.1, U1.A8 (!RESET)
MIC_OUTPUT: C55.2, U1.A4 (PC30/I14/AIN1.12)
unnamed: L6.1, U1.A6 (VSW)
unnamed: R12.2, U1.F2 (PA03/I3/VREFA/AIN0.1)
unnamed: D2.1, F1.1, USB1.A4_B9 (A4/B9/VBUS), USB1.B4_A9 (B4/A9/VBUS)
unnamed: R1.2, USB1.A5 (A5/CC1)
unnamed: R2.2, USB1.B5 (B5/CC2)
unnamed: Q4.3 (D), R6.2
unnamed: BUZ1.-, D5.+, R6.1
unnamed: Q4.1 (G), R5.2, R7.2
unnamed: C12.1, R35.1, U4.3 (SCL)
unnamed: ANT2.2, C28.2, L3.1
unnamed: R69.1, U1.K15 (PC22/I6/SERCOM1.0+3.1/TCC0.6)
unnamed: R68.1, U1.J14 (PC23/I7/SERCOM1.1+3.0/TCC0.7)
unnamed: Q7.1 (G), Q8.3 (D), R91.1, SW3.2
unnamed: C13.1, R57.1, U4.4 (D/C)
unnamed: R65.2, U10.23
unnamed: R74.1, U4.5 (CS)
unnamed: C43.1, R75.1, U4.6 (SDA)
unnamed: R10.2, U10.22
unnamed: Q13.3 (D), R83.2
unnamed: Q13.1 (G), R47.1, R80.1
unnamed: C42.1, R76.1, U4.7 (SDO)
unnamed: Q9.1 (G), Q14.1 (G), Q16.3 (D), R93.2, R94.1
unnamed: R66.1, U10.7
unnamed: R67.1, U10.10
unnamed: R46.1, U4.11 (LEDK), U4.12 (LEDK), U4.13 (LEDK), U4.14 (LEDK)
unnamed: Q2.1 (G), R19.1, R20.2, U9.4 (Y)
unnamed: Q1.1 (G), R16.1, R17.1
unnamed: C34.2, R23.1, R24.2
unnamed: R18.2, R21.1, U9.1 (!OE!), U9.2 (A)
unnamed: LED1.1 (+), R31.2
unnamed: R24.1, U2.3 (+IN1)
unnamed: C4.2, C5.2, F1.2, Q2.3 (D)
unnamed: C34.1, MIC1.1 (+), R22.2
unnamed: R25.2, R26.1, U2.2 (-IN1)
unnamed: R26.2, U2.1 (OUT1), U2.5 (+IN2)
unnamed: R27.1, R28.2, U2.6 (-IN2)
unnamed: C50.2, U1.B1 (PA01/I1/SERCOM1.1/TC2.1), X2.1
unnamed: C36.1, C37.1, C38.1, L6.2, U1.A7 (VDDCORE)
unnamed: R39.2, U4.15 (XL)
unnamed: C49.2, U1.A1 (PA00/I0/SERCOM1.0/TC2.0), X2.2
unnamed: C35.1, R9.1, R30.1
unnamed: R40.2, U4.16 (YU)
unnamed: Q11.2 (B), Q11.5 (B), Q11.6 (C), R98.2
unnamed: R41.2, U4.17 (XR)
unnamed: R42.2, U4.18 (YD)
unnamed: R81.1, U10.9
unnamed: Q1.3 (D), R46.2
unnamed: R82.1, U10.8
unnamed: R77.2, R79.1, U8.2-1 (2), U8.2-2 (2)
unnamed: Q10.1 (G), Q11.3 (C), R97.2
unnamed: D10.-, R83.1
unnamed: Q8.1 (G), R29.1, SW3.4
unnamed: Q9.3 (D), Q14.3 (D)
unnamed: C52.1, R8.2, X4.1 (X1)
unnamed: R50.1, U1.C1 (PC00/I1/ADC1.10)
unnamed: D7.2 (-), Q3.3 (D)
unnamed: D7.1 (+), R51.2
unnamed: Q3.1 (G), R52.2, R53.2
unnamed: D15.1 (14), D15.14, J1.8 (DATA1), R60.1
unnamed: Q12.3 (D), Q15.3 (D)
unnamed: Q16.1 (G), R88.2, R100.2
unnamed: C55.1, R27.2, U2.7 (OUT2)
unnamed: Q12.1 (G), Q15.1 (G), R95.2, R96.1, R99.1
unnamed: L5.1, U12.3 (SW)
unnamed: D15.7 (8), D15.8, J1.1 (DATA2), R64.1
unnamed: R71.1, R72.2
unnamed: C27.2, L3.2, U10.31
unnamed: R70.1, R71.2, U12.7 (FB)
unnamed: D15.2 (13), D15.13, J1.7 (DO), R43.1
unnamed: D15.3 (12), D15.12, J1.5 (SCLK), R44.1
unnamed: D15.4 (11), D15.11, J1.3 (DI), R45.1
PWR_EN: Q7.3 (D), R73.1, R78.2, R90.2, U12.8 (EN), U13.3 (!SHUTDOWN)
RPI_3V3: Q10.3 (D), Q11.1 (E), Q15.2 (S), U3.1 (3V3), U3.17 (3V3)
RPI_5V: D9.+, Q14.2 (S), R20.1, U3.2 (5V0), U3.4 (5V0)
RTL8720D_CHIP_PU: C9.1, J2.5, J3.10, R11.1, U1.P15 (PA18/I2/SERCOM1+3.2/TC3.0+TCC1.2+0.6/PTC), U10.24
RTL8720D_HSPI_CLK: R10.1, R66.2, U1.B13 (PB25/SERCOM0.1+2.0/QDI.2)
RTL8720D_HSPI_CS: R82.2, U1.B10 (PC25/I9/SERCOM0+2.3/TRACEDATA.2)
RTL8720D_HSPI_MISO: R81.2, U1.A11 (PC24/I8/SERCOM0+2.2/TRACEDATA.3)
RTL8720D_HSPI_MOSI: R65.1, R67.2, U1.B14 (PB24/I8/SERCOM0.0+2.1/QDI.1)
RTL8720D_RXD: J2.4, J3.9, R69.2, U10.26
RTL8720D_TXD: J2.3, J3.8, R68.2, U10.25
RXD: U1.B12 (PB27/I13/SERCOM2.1+4.0/TCC1.3), U3.10 (RXD0/GPIO15)
SD_CS: D15.6 (9), D15.9, J1.2 (CS), R63.1, U1.L14 (PC19/I3/SERCOM6+0.3/TCC0.3)
SD_DET: D8.2, J1.9 (CDN), R36.1, U1.H14 (PD21/I11/SERCOM1+3.3/TCC1.1/SDHC1.SDWP)
SD_MISO: R43.2, R61.1, U1.M15 (PC18/I2/SERCOM6.2+0.2/TCC0.2/QDI.2)
SD_MOSI: R45.2, R62.1, U1.N15 (PC16/I0/SERCOM6.0+0.1/TCC0/QDI.0)
SD_SCK: R44.2, U1.M14 (PC17/I1/SERCOM6.1+0.0/TCC0.1/QDI.1)
SPI_CS: U1.B3 (PB01/I1/AIN0.13/SERCOM5.3/TC7.1/PTC), U3.24 (!CE0!/GPIO8)
SPI_MISO: J6.2, U1.A3 (PB00/I0/AIN0.12/SERCOM5.2/TC7.0/PTC), U3.21 (GPIO9/MISO)
SPI_MOSI: J6.1, U1.A2 (PB02/I2/AIN0.14/SERCOM5.0/TC6.0+TCC2.2/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), U3.19 (GPIO10/MOSI)
SPI_SCK: J6.3, U1.B2 (PB03/I3/AIN0.15/SERCOM5.1/TC6.1/PTC), U3.23 (GPIO11/SCLK)
SWDCLK: J3.1, J7.1, R33.2, R38.2, U1.B7 (PA30/I14/SERCOM1.2/SWCLK)
SWDIO: J3.2, J7.2, R34.2, R54.1, U1.B6 (PA31/I15/SERCOM1.3/SWDIO)
SWITCH_B: R86.1, SW1.4, U1.R8 (PD12/I7/TCC0.5)
SWITCH_U: R87.1, SW1.6, U1.J15 (PD20/I10/SERCOM1+3.2/TCC1.0/SDHC1.SDCD)
SWITCH_X: R37.1, SW1.1, U1.R6 (PD08/I3/SERCOM7.0+6.1/TCC0.1)
SWITCH_Y: R85.1, SW1.3, U1.P8 (PD09/I4/SERCOM7.1+6.0/TCC0.2)
SWITCH_Z: R84.1, SW1.2, U1.R7 (PD10/I5/SERCOM7+6.2/TCC0.3)
SWO: J3.3, J7.3, U1.A5 (PB30/I14/SERCOM5.1/TC0.0+TCC4.0+0.6/SWO)
SYNC: R102.1, U1.N14 (PA19/I3/SERCOM1+3.3/TC3.1+TCC1.3+0.7/PT), U10.3
TXD: U1.A13 (PB26/I12/SERCOM2.0+4.1/TCC1.3), U3.8 (TXD0/GPIO14)
USB_5V: C3.2, C8.1, C66.2, C67.2, D9.-, J6.19, J6.20, Q2.2 (S), Q7.2 (S), Q8.2 (S), Q9.2 (S), R29.2, R73.2, R90.1, R94.2, U12.2 (VIN), U13.1 (VIN)
USB_D+: R56.1, U1.B15 (PA25/19/SERCOM3+5.3/D+)
USB_D-: R55.2, U1.C15 (PA24/I8/SERCOM3+5.2/D-)
USB_HOST_EN: R21.2, U1.B8 (PA27/I11)
USER_LED: R53.1, U1.R14 (PA15/I15/SERCOM2+4.3/TC3.1+TCC2.1+1.3)
VCC3V3_8720: C1.2, C2.2, C6.2, C7.1, C10.1, J2.1, R11.2, R102.2, R103.2, U10.16, U13.5 (VOUT)
VCC3V3_MCU_A: C33.1, C60.1, L2.1, R12.1, R22.1, U1.G6 (VDDANA0), U1.M2 (VDDANA1), U2.8 (+V)
VCC3V3_MCU_D: C15.1, C16.1, C39.1, C40.1, C41.1, C48.1, C62.1, D1.2, FB3.2, J1.4 (VDD), J7.6, R3.2, R4.2, R9.2, R32.2, R36.2, R37.2, R38.1, R49.2, R51.1, R58.2, R59.2, R60.2, R61.2, R62.2, R63.2, R64.2, R84.2, R85.2, R86.2, R87.2, U1.F7 (VDDIO7), U1.F8 (VDDIO6), U1.F10 (VDDIO5), U1.H10 (VDDIO4), U1.K6 (VDDIOB1), U1.K7 (VDDIOB2), U1.K10 (VDDIO3), U14.8 (VCC)
VCC_3V3: BUZ1.+, C11.2, C14.2, C32.1, C53.1, C54.1, C61.1, C63.+, C64.2, C65.2, D5.-, D10.+, FB2.1, FB3.1, J4.3, J5.3, J6.15, J6.16, L2.2, L5.2, Q10.2 (S), Q11.4 (E), Q12.2 (S), R13.1, R14.1, R18.1, R31.1, R70.2, R96.2, U5.1 (VDD_IO), U5.8 (CS), U5.14 (VDD), U8.1-1 (1), U8.1-2 (1), U9.5 (VCC), U11.8 (VCC), U12.5 (OUT)
XIN: R8.1, U1.A15 (PB22/I6/SERCOM1+5.2/TC7.0/QDI.2)
XOUT: C51.1, U1.A14 (PB23/I7/SERCOM1+5.3/TC7.1/QDI.0), X4.3 (X2)

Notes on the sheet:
First version
20190812
Milo
Power
ATSAMD51P19A
Buzzer & MIC
WIFI+BLE
Gyroscope & LCD
8720 module Download
Replace with 0R resistance
USB HOST selection Power selection
Close to USB TYPE C
Close to ATSAMD51P19A power Pin
Header Interface and Button
Input current:2A
Output current:2A
Input current 500mA
Input current 600mA
ATSAMD51P19A Download
I2C Address 0x19
To guarantee the XOSC32K behavior in crystal mode,PC00 must be static
MCU Reset
Power ON
Power OFF
PA28/CTS/PWM6/RREF
PB17/SPI_DATA1
PB16/SPI_CS
PB13/SPI_CLK
PB14/SPI_DATA0
ADC6
ADC4/TXD
ADC5/RXD/I2C_SDA
PA25/RXD/USB_DM/I2C_SCL
PA26/TXD/USB_DP
PA30/PWM7/SWD_CLK
PA27/RTS/SWD_DATA
PB20/TXD/PWM12/I2S_CLK/SPI_DATA0/I2C_SCL
PB21/RXD/PWM13/I2S_WS/SPI_CLK/I2C_SDA
PA15/CTS/CS
PA14/RTS/CLK/I2S_TX2

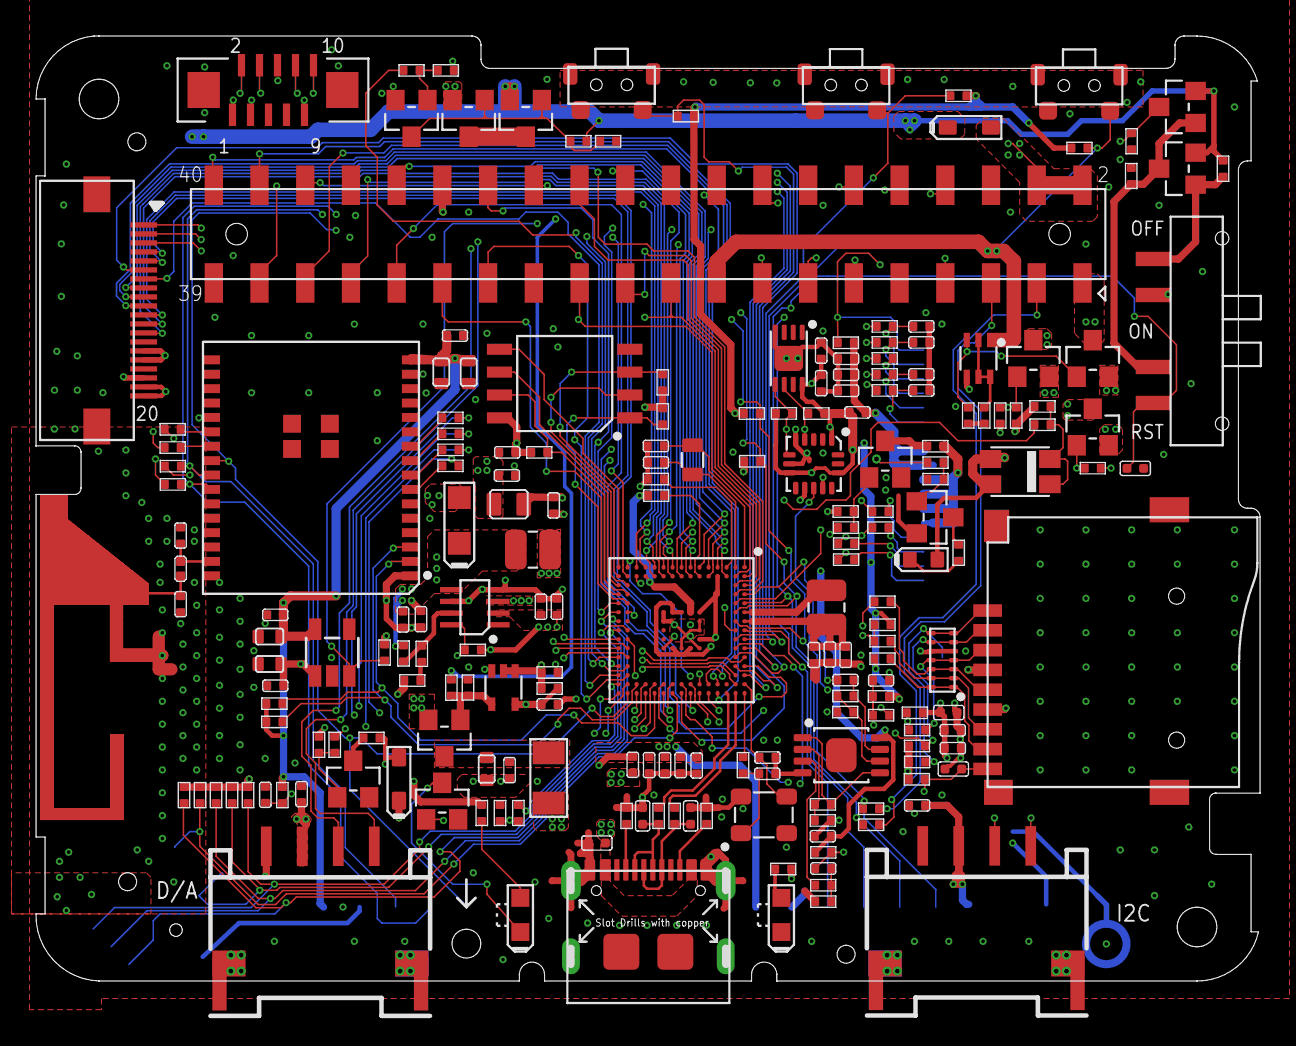
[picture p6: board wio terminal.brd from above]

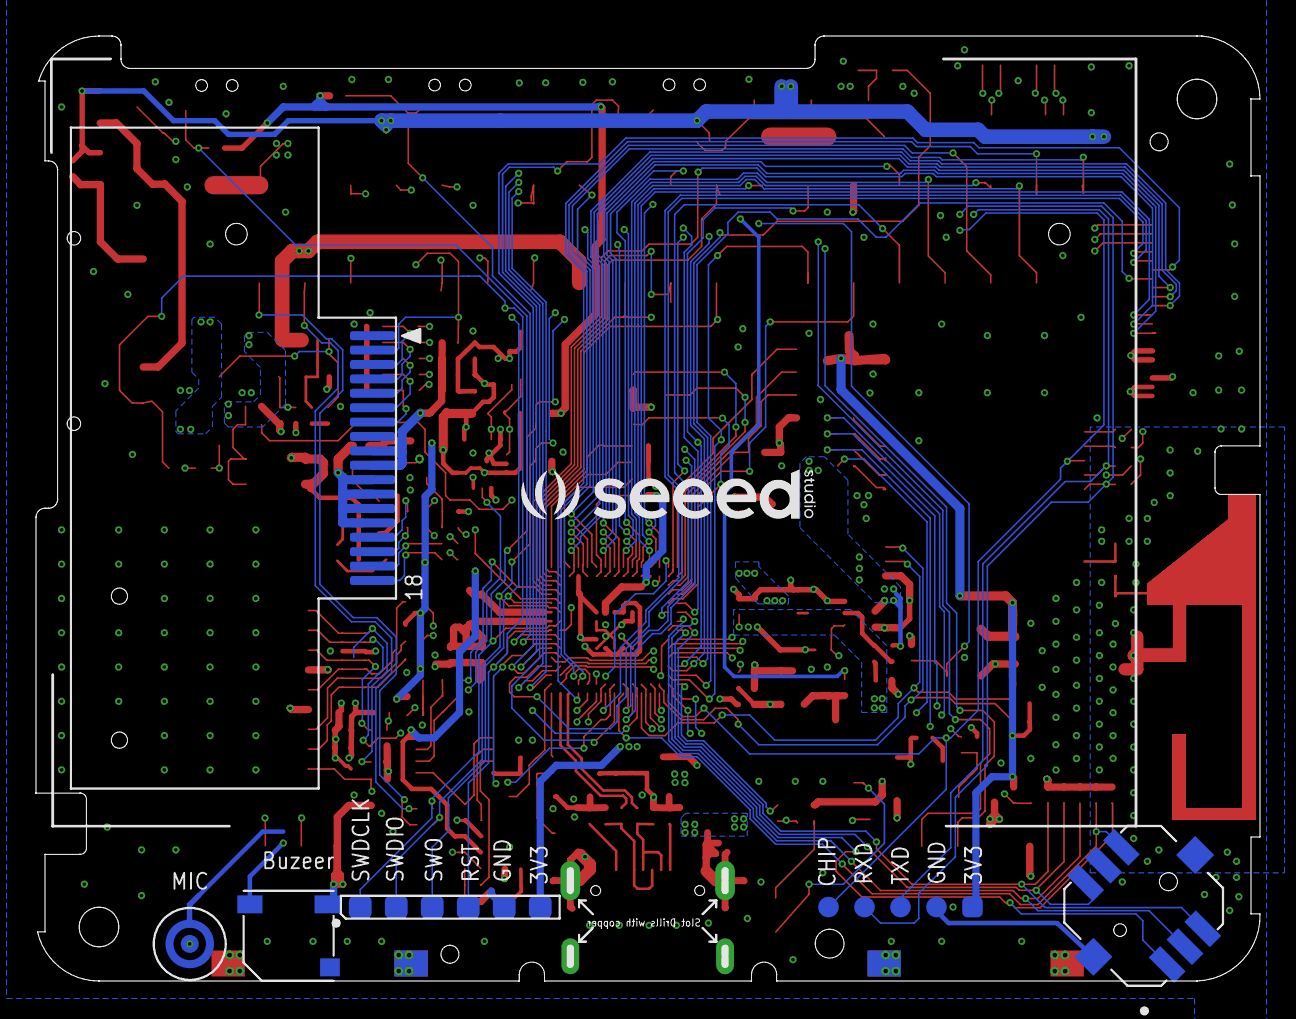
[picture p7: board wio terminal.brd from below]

Board: 4 copper layers, 68.0 x 52.5 mm, 212 parts (8 on the bottom side), 177 nets.

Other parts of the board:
U$2: LOGO-SEEED-VECTOR; SEEED-SILK-VECTOR

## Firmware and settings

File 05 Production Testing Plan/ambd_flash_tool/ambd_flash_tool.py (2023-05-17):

import os
import sys
import platform
import shutil
import struct
import re
import time

try:
    import pathlib
except ImportError:
    print("Installing pathlib module")
    res = os.system("pip3 install pathlib")
    if res != 0:
        print("pathlib module installation failed")
        sys.exit(1)
    import pathlib

from pathlib import Path

try:
    import click
except ImportError:
    print("Installing click module")
    res = os.system("pip3 install click")
    if res != 0:
        print("click module installation failed")
        sys.exit(1)
    import click

try:
    import colorama
except ImportError:
    print("Installing colorama module")
    res = os.system("pip3 install colorama")
    if res != 0:
        print("Colorama module installation failed")
        sys.exit(1)
    import colorama

from colorama import init, Fore, Back, Style

try:
    import serial
except ImportError:
    print("Installing pyserial module")
    res = os.system("pip3 install pyserial")
    if res != 0:
        print("pyserial module installation failed")
        sys.exit(1)
    import serial

if os.name == 'nt':  # sys.platform == 'win32':
    from serial.tools.list_ports_windows import comports
elif os.name == 'posix':
    from serial.tools.list_ports_posix import comports
else:
    raise ImportError("Sorry: no implementation for your platform ('{}') available".format(os.name))

# List of supported board USB IDs.  Each board is a tuple of unique USB vendor
# ID, USB product ID.
BOARD_IDS = \
    [{
        "name": "wio terminal",
        "info": ("2886", "802D"),
        "isbootloader": False
    },
    {
        "name": "wio terminal",
        "info": ("2886", "002D"),
        "isbootloader": True
    }]

def getAllPortInfo():
    return comports(include_links=False)
    
def getAvailableBoard():
    for info in getAllPortInfo():
        port, desc, hwid = info 
        ii = hwid.find("VID:PID")
        #hwid: USB VID:PID=2886:002D SER=4D68990C5337433838202020FF123244 LOCATION=7-3.1.3:1.
        if ii != -1:
            for b in  BOARD_IDS:
                (vid, pid) = b["info"]
                if vid == hwid[ii + 8: ii + 8 + 4] and pid == hwid[ii + 8 + 5 :ii + 8 + 5 + 4 ]:
                    if b["isbootloader"] == True :
                        return port, True
                    else:
                        return port, False
    return None, False

def stty(port):
    
    if port == None:
        _port, _isbootloader = getAvailableBoard()
        if _port == None:
            print(Fore.RED + "Sorry, the device you should have is not plugged in.")
            sys.exit(1)
    else:
        _port = port

    if os.name == "posix":
        if platform.uname().system == "Darwin":
            return "stty -f " + _port + " %d"
        return "stty -F " + _port + " %d"
    elif os.name == "nt":
        return "MODE " + _port + ":BAUD=%d PARITY=N DATA=8"
    
    return "echo not support"

def get_flash_tool():
    _tool = str(Path(os.path.split(os.path.realpath(__file__))[0], 'tool'))
    _platform = platform.platform()
    if _platform.find('Windows') >= 0:
        _tool = str(Path(_tool, 'windows', "amebad_image_tool.exe"))
    elif _platform.find('Linux') >= 0:
        _tool = str(Path(_tool, 'linux', 'amebad_image_tool'))
    elif _platform.find('Darwin') >= 0:
        _tool = str(Path(_tool, 'macos', 'amebad_image_tool'))
    elif _platform.find('macOS') >= 0:
        _tool = str(Path(_tool, 'macos', 'amebad_image_tool'))
    else:
        _tool = ""
        print(Fore.RED, "No support yet!")
        sys.exit(1)
    return _tool

def get_bossac_tool():
    _tool = str(Path(os.path.split(os.path.realpath(__file__))[0], 'tool'))
    _platform = platform.platform()
    if _platform.find('Windows') >= 0:
        _tool = str(Path(_tool, 'windows', "bossac.exe"))
    elif _platform.find('Linux') >= 0:
        _tool = str(Path(_tool, 'linux', 'bossac'))
    elif _platform.find('Darwin') >= 0:
        _tool = str(Path(_tool, 'macos', 'bossac'))
    elif _platform.find('macOS') >= 0:
        _tool = str(Path(_tool, 'macos', 'bossac'))
    else:
        _tool = ""
        print(Fore.RED, "No support yet!")
        sys.exit(1)
    return _tool


def make_empty_img(length):
    _empty = struct.pack('B', 0xFF)
    with open("km0_boot_all.bin", "wb") as _km0_boot_all_bin:
        for i in range(8192):
            i
            _km0_boot_all_bin.write(_empty)
    _km0_boot_all_bin.close()

    with open("km4_boot_all.bin", "wb") as _km4_boot_all_bin:
        for i in range(4096):
            i
            _km4_boot_all_bin.write(_empty)
    _km4_boot_all_bin.close()

    with open("km0_km4_image2.bin", "wb") as _km0_km4_image2_bin:
        for i in range(length - 12):
            i
            for j in range(1024):
                j
                _km0_km4_image2_bin.write(_empty)
    _km0_km4_image2_bin.close()

def copy_img(dir):
    _local_dir = str(Path(os.path.split(os.path.realpath(__file__))[0]))
    _km0_boot_all_bin = str(Path(dir, "km0_boot_all.bin"))
    _km4_boot_all_bin = str(Path(dir, "km4_boot_all.bin"))
    _km0_km4_image2_bin = str(Path(dir, "km0_km4_image2.bin"))
    if not os.path.exists(_km0_boot_all_bin):
        print(Fore.RED + _km0_boot_all_bin + " not exists!")
        sys.exit(1)
    if not os.path.exists(_km4_boot_all_bin):
        print(Fore.RED + _km4_boot_all_bin + " not exists!")
        sys.exit(1)
    if not os.path.exists(_km0_km4_image2_bin):
        print(Fore.RED + _km0_km4_image2_bin + " not exists!")
        sys.exit(1)
    print(Fore.GREEN + "copy img to workspace...")
    shutil.copyfile(_km0_boot_all_bin, str(Path(_local_dir, "km0_boot_all.bin")))
    shutil.copyfile(_km4_boot_all_bin, str(Path(_local_dir, "km4_boot_all.bin")))
    shutil.copyfile(_km0_km4_image2_bin, str(Path(_local_dir, "km0_km4_image2.bin")))

    
@click.group()
@click.version_option(version='0.6.0')
def cli():
    """RTL872XD Flash tool

    This tool is used to burn rtl8720d firmware.
    """
    init(autoreset=True)
    pass

@cli.command()
@click.option(
    "--length",
    "-l",
    default=2048,
    type=click.INT,
    help="Length(kB) (default 2048kB).",
    metavar="DELAY",
)
@click.option(
    "--port",
    "-p",
    required=False,
    type=click.STRING,
    help="Name of serial port for connected board.",
    metavar="PORT",
)
def erase(length, port):
    if port == None:
        _port, _isbootloader = getAvailableBoard()
        if _port == None:
            print(Fore.RED + "Sorry, the device you should have is not plugged in.")
            sys.exit(1)
    else:
        _port = port
    
    if _isbootloader == False:
        _cmd = stty(_port)
        print(_cmd)
        if _cmd != "echo not support":
            os.system(_cmd%1200)
        time.sleep(2)
    _port, _isbootloader = getAvailableBoard()
    if _isbootloader == True:
        _tool = get_bossac_tool()
        _cmd = _tool + " -i -d --port=" + _port + " -U -i --offset=0x4000 -w -v " + str(Path(os.getcwd(), 'firmware')) + "/WioTerminal_USB2Serial_Burn8720.ino.bin -R" 
        os.system(_cmd)
   
    for i in range(0, 3):
        print(Fore.GREEN + "wait...")
        time.sleep(1)

    _port, _isbootloader = getAvailableBoard()
    if _port == None:
        print(Fore.RED + "Sorry, the device you should have is not plugged in.")
        sys.exit(1)

    make_empty_img(length)

    _tool = get_flash_tool()
    
    _cmd = _tool + " " + _port 

    print(Fore.GREEN + "Flashing...")
    obj = os.popen(_cmd)
    ret = obj.read()
    print(ret)
    if ret.find('successfully') >= 0:
        print(Fore.GREEN + "Success!")
    else:
        print(Fore.RED + "Error!")
        sys.exit(2)

@cli.command()
@click.option(
    "--port",
    "-p",
    required=False,
    type=click.STRING,
    help="Name of serial port for connected board.",
    metavar="PORT",
)
@click.option(
    "--dir",
    "-d",
    required=False,
    type=click.STRING,
    help="Specifies the location of the directory where the firmware is located",
    metavar="DIR",
)
def flash(port, dir):
    if port == None:
        _port, _isbootloader = getAvailableBoard()
        if _port == None:
            print(Fore.RED + "Sorry, the device you should have is not plugged in.")
            sys.exit(1)
    else:
        _port = port

    print(_port)
    
    if _isbootloader == False:
        _cmd = stty(_port)
        print(_cmd)
        if _cmd != "echo not support":
            os.system(_cmd%1200)
        time.sleep(2)
    _port, _isbootloader = getAvailableBoard()
    if _isbootloader == True:
        _tool = get_bossac_tool()
        _cmd = _tool + " -i -d --port=" + _port + " -U -i --offset=0x4000 -w -v " + str(Path(os.getcwd(), 'firmware')) + "/WioTerminal_USB2Serial_Burn8720.ino.bin -R" 
        os.system(_cmd)

    for i in range(0, 3):
        print(Fore.GREEN + "wait...")
        time.sleep(1)

    _port, _isbootloader = getAvailableBoard()

    if _port == None:
        print(Fore.RED + "Sorry, the device you should have is not plugged in.")
        sys.exit(1)

    if dir == None:
        dir = str(Path(os.getcwd(), 'firmware'))
  
    copy_img(dir)

    _tool = get_flash_tool()
    
    _cmd = _tool + " " + _port 

    print(Fore.GREEN + "Flashing...")
    obj = os.popen(_cmd)
    ret = obj.read()
    print(ret)
    if ret.find('successfully') >= 0:
        print(Fore.GREEN + "Success!")
    else:
        print(Fore.RED + "Error!")
        sys.exit(3)

if __name__ == "__main__":
    try:
        cli()
    except OSError:
        print("error")
        sys.exit(4)
   

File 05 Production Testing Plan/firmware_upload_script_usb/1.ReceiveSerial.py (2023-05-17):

import serial
from serial.tools import list_ports
from time import sleep



def find_device():
    while True:
        port = None
        for p in list_ports.comports():
#            print p[2]
            if p[2].upper().startswith('USB VID:PID=2886:802D'):
                port = p[0]
                print('find Wio terminal port: ' + port)
                return port

        sleep(0.1)

        
Wio_port=find_device()
WioSerial = serial.Serial(port=Wio_port,baudrate=115200,bytesize=8,stopbits=1,timeout=1)
while True:
    line = WioSerial.readline().strip()
    if line !="":
        print line
    if "RTL8720 Wireless PASS" in line:
        break

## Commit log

2023-05-17 Delete: delete readme files
    [Bill_of_Materials-WioTerminal.xls]
2023-05-23 Update: Update the readme files and upload the Design files in wiki
    [D51R in Wio Terminal.xlsx, Wio-Terminal-Chassis-Battery.dxf, Wio-Terminal-Main-Back-V3.0-White-72x57x7.1mm.dxf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]

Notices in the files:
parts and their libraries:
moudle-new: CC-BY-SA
